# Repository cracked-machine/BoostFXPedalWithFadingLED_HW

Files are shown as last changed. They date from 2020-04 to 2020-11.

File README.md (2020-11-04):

## Boost Pedal with LEDs

- Required Kicad Hardware library: https://github.com/cracked-machine/KicadLibrary
- Related SW project: https://github.com/cracked-machine/BoostFXPedalWithFadingLED__SW

This is a simple opamp-based gain boost circuit for guitar FX pedal.

The sockets and switches are wired directly to the board, they are not panel-mounted. This makes the design simpler but construction becomes more time-consuming. Mechanical layout for the enclosure is below.

Mechanical Layout

This design went through several revisions.

- RevA is a purely analog HW design without any LEDs.
- RevC added a micro-controller to run 8 SMT LEDs in a fading pattern using PWM. RevC uses multiple SPST solid-state switches (DG467) to simplify the footswitch control and replace the bulky and expensive 3PDT mechanical switches often used in guitar FX pedals. Some high frequency signal attenuation could be heard with the DG467 switches. This is probably due to the MOSFET capacitance of the DG467 switches. However, [FFT analysis](OverdrivePedal_RevC/OverDriveSpectrumAnalysis) was inconclusive.
- RevD proposes a design to use a single DPDT Relay to avoid any signal loss issues. However, this revision was not constructed/tested.

Revision|Comments|Schema|Front|Back
:--------:|:--:|:--:|:--:|:---:
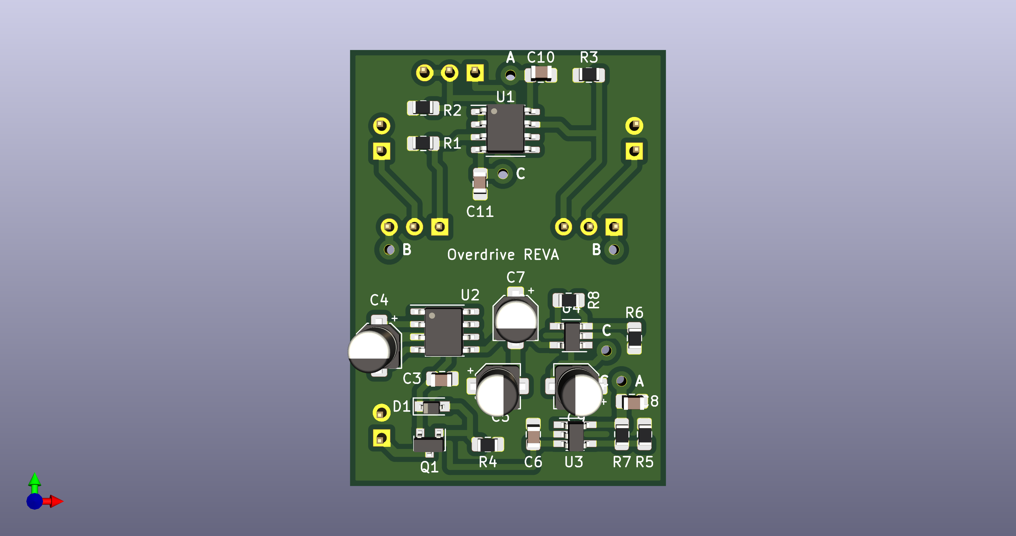
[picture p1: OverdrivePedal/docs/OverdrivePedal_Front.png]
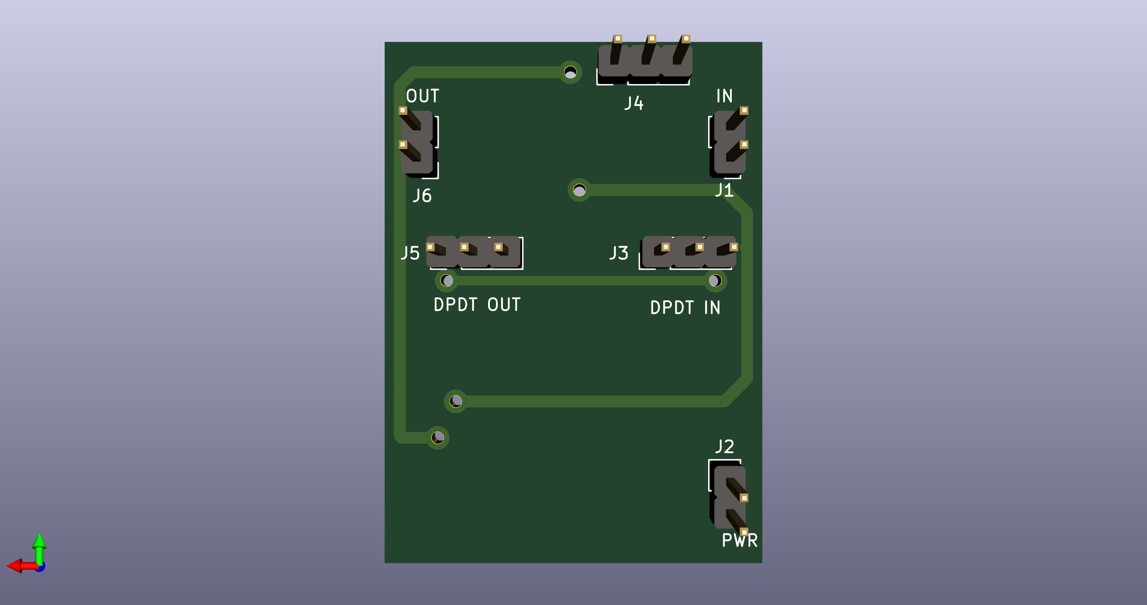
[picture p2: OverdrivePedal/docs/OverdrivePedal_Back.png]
RevA|Without LEDs|[link](OverdrivePedal/docs/OverdrivePedal.pdf)|||
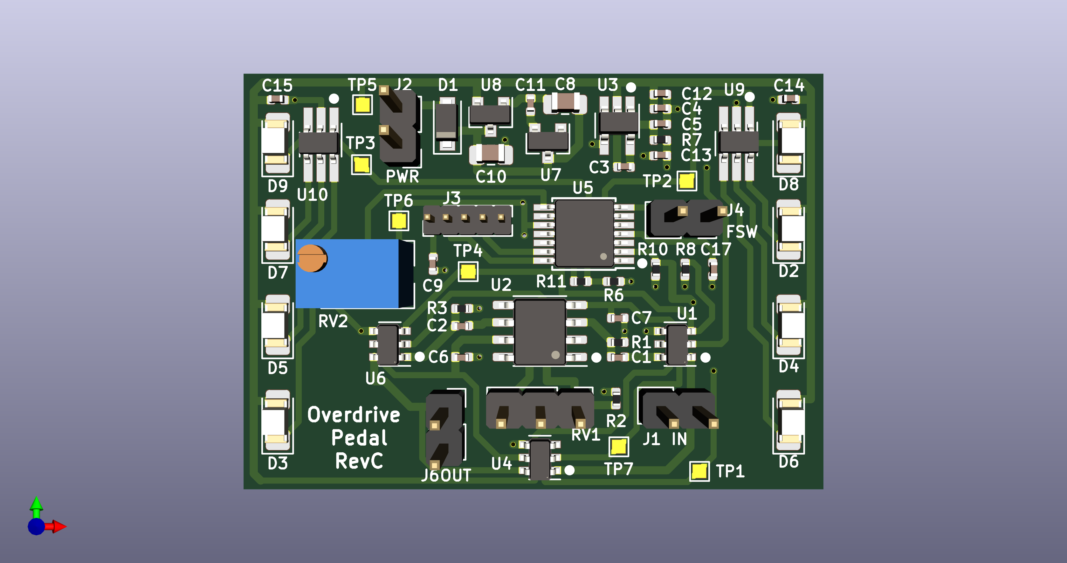
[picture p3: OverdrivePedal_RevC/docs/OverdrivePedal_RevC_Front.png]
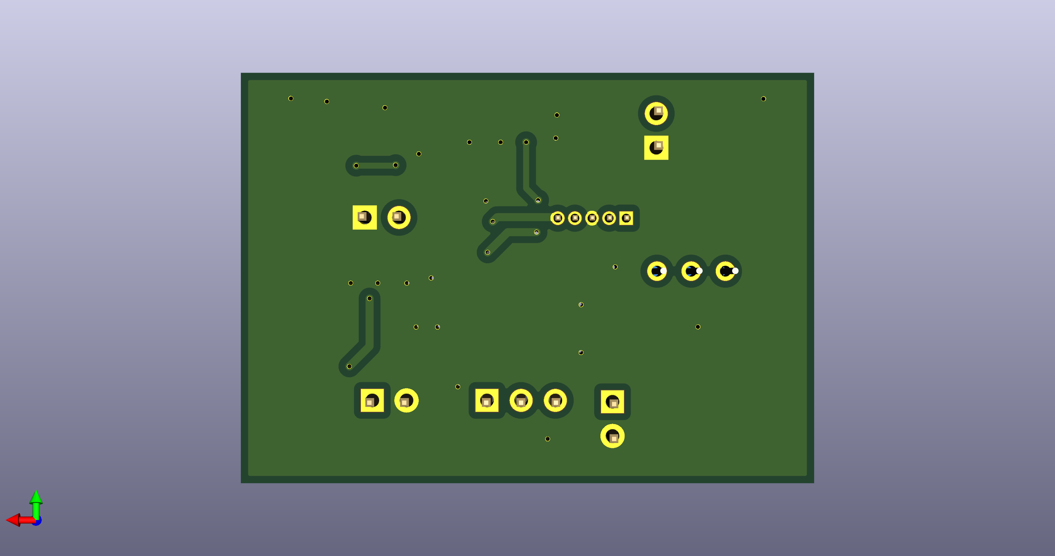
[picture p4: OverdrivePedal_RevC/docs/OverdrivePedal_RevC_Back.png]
RevC|With LEDs, SPST SolidState|[link](OverdrivePedal_RevC/docs/OverdrivePedal_RevC.pdf)|||
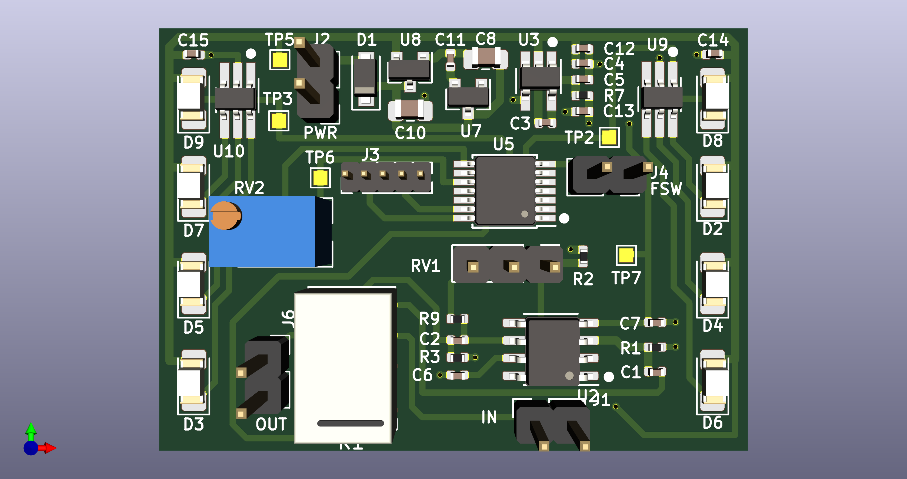
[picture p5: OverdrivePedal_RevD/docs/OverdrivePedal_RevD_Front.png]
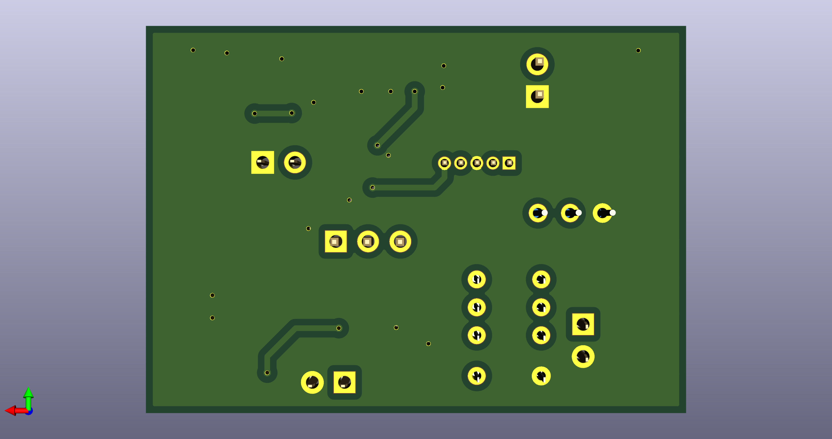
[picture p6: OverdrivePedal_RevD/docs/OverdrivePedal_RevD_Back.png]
RevD|With LEDs, DPDT Relay|[link](OverdrivePedal_RevD/docs/OverdrivePedal_RevD.pdf)|||

### Demo of RevC

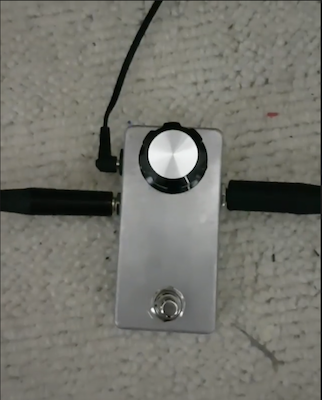
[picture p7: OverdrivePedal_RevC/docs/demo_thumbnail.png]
Boost Pedal with LEDs RevC (https://instagram.flhr4-2.fna.fbcdn.net/v/t50.2886-16/101602450_255417275813723_5445158146007316454_n.mp4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 "Boost Pedal with LEDs RevC")


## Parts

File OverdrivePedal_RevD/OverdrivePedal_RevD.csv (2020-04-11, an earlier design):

Source: | /home/chris/Projects/Hardware/OverdrivePedal/OverdrivePedal_RevB/OverdrivePedal_RevB.sch
Date: | Thu 09 Apr 2020 17:33:00 BST
Tool: | Eeschema 5.1.5-52549c5~86~ubuntu18.04.1
Generator: | /usr/share/kicad/plugins/bom_csv_grouped_by_value.py
Component Count: | 55
Individual Components:
Item | Qty | Reference(s) | Value | LibPart | Footprint | Datasheet
 |  | C1 | C | Device:C | Capacitor_SMD:C_0402_1005Metric | ~
 |  | C2 | C | Device:C | Capacitor_SMD:C_0402_1005Metric | ~
 |  | C3 | 1uF | Device:C | Capacitor_SMD:C_0402_1005Metric | ~
 |  | C4 | 1uF | Device:C | Capacitor_SMD:C_0402_1005Metric | ~
 |  | C5 | 1uF | Device:C | Capacitor_SMD:C_0402_1005Metric | ~
 |  | C6 | 100nF | Device:C | Capacitor_SMD:C_0402_1005Metric | ~
 |  | C7 | 100nF | Device:C | Capacitor_SMD:C_0402_1005Metric | ~
 |  | C8 | 1uF | Device:C | Capacitor_SMD:C_0805_2012Metric_Pad1.15x1.40mm_HandSolder | ~
 |  | C9 | 100nF | Device:C | Capacitor_SMD:C_0402_1005Metric | ~
 |  | C10 | 1uF | Device:C | Capacitor_SMD:C_0805_2012Metric_Pad1.15x1.40mm_HandSolder | ~
 |  | C11 | 10uF | Device:C | Capacitor_SMD:C_0402_1005Metric | ~
 |  | C12 | 10uF | Device:C | Capacitor_SMD:C_0402_1005Metric | ~
 |  | C13 | 1nF | Device:C | Capacitor_SMD:C_0402_1005Metric | ~
 |  | C14 | 1u | Device:C | Capacitor_SMD:C_0402_1005Metric | ~
 |  | C15 | 1u | Device:C | Capacitor_SMD:C_0402_1005Metric | ~
 |  | C16 | 1uF | Device:C | Capacitor_SMD:C_0402_1005Metric | ~
 |  | C17 | 100nF | Device:C | Capacitor_SMD:C_0402_1005Metric | ~
 |  | C18 | 1uF | Device:C | Capacitor_SMD:C_0402_1005Metric | ~
 |  | C19 | 1uF | Device:C | Capacitor_SMD:C_0402_1005Metric | ~
 |  | C20 | 1nF | Device:C | Capacitor_SMD:C_0402_1005Metric | ~
 |  | D1 | BYS12-90 | Device:D_Schottky | Diode_SMD:D_SOD-123F | ~
 |  | D2 | LED | Device:LED | LED_SMD:LED_1206_3216Metric_Pad1.42x1.75mm_HandSolder | ~
 |  | D3 | LED | Device:LED | LED_SMD:LED_1206_3216Metric_Pad1.42x1.75mm_HandSolder | ~
 |  | D4 | LED | Device:LED | LED_SMD:LED_1206_3216Metric_Pad1.42x1.75mm_HandSolder | ~
 |  | D5 | LED | Device:LED | LED_SMD:LED_1206_3216Metric_Pad1.42x1.75mm_HandSolder | ~
 |  | D6 | LED | Device:LED | LED_SMD:LED_1206_3216Metric_Pad1.42x1.75mm_HandSolder | ~
 |  | D7 | LED | Device:LED | LED_SMD:LED_1206_3216Metric_Pad1.42x1.75mm_HandSolder | ~
 |  | D8 | LED | Device:LED | LED_SMD:LED_1206_3216Metric_Pad1.42x1.75mm_HandSolder | ~
 |  | D9 | LED | Device:LED | LED_SMD:LED_1206_3216Metric_Pad1.42x1.75mm_HandSolder | ~
 |  | J1 | AudioJack2-Connector | audiojack2-connector_numbered:AudioJack2-Connector | Connector_PinSocket_2.54mm:PinSocket_1x02_P2.54mm_Vertical
 |  | J2 | Barrel_Jack | Connector:Barrel_Jack | Connector_PinHeader_2.54mm:PinHeader_1x02_P2.54mm_Vertical | ~
 |  | J3 | Conn_01x05 | Connector_Generic:Conn_01x05 | Connector_PinSocket_2.54mm:PinSocket_1x05_P2.54mm_Vertical | ~
 |  | J4 | SW_SPST | Switch:SW_SPST | Connector_PinSocket_2.54mm:PinSocket_1x02_P2.54mm_Vertical | ~
 |  | J6 | AudioJack2-Connector | audiojack2-connector_numbered:AudioJack2-Connector | Connector_PinSocket_2.54mm:PinSocket_1x02_P2.54mm_Vertical
 |  | R1 | 22M | Device:R | Resistor_SMD:R_0402_1005Metric | ~
 |  | R2 | 2K7 | Device:R | Resistor_SMD:R_0402_1005Metric | ~
 |  | R3 | 10K | Device:R | Resistor_SMD:R_0402_1005Metric | ~
 |  | R4 | 10K | Device:R | Resistor_SMD:R_0402_1005Metric | ~
 |  | R5 | 100R | Device:R | Resistor_SMD:R_0402_1005Metric | ~
 |  | R7 | 100R | Device:R | Resistor_SMD:R_0402_1005Metric | ~
 |  | R8 | 10K | Device:R | Resistor_SMD:R_0402_1005Metric | ~
 |  | R10 | 10K | Device:R | Resistor_SMD:R_0402_1005Metric | ~
 |  | R11 | 10K | Device:R | Resistor_SMD:R_0402_1005Metric | ~
 |  | RV1 | B10K | Device:R_POT | Connector_PinHeader_2.54mm:PinHeader_1x03_P2.54mm_Vertical | ~
 |  | U1 | DG468DV_T1_E3 | DG46x:DG468DV_T1_E3 | Package_SO:TSOP-6_1.65x3.05mm_P0.95mm | https://www.vishay.com/docs/74413/dg467.pdf
 |  | U2 | TL071 | Amplifier_Operational:TL071 | Package_SO:SOIC-8_3.9x4.9mm_P1.27mm | http://www.ti.com/lit/ds/symlink/tl071.pdf
 |  | U3 | TPS60400 | TPS6040x:TPS60400 | Package_TO_SOT_SMD:SOT-23-5_HandSoldering | http://www.ti.com/lit/ds/symlink/tps60402.pdf
 |  | U4 | DG468DV_T1_E3 | DG46x:DG468DV_T1_E3 | Package_SO:TSOP-6_1.65x3.05mm_P0.95mm | https://www.vishay.com/docs/74413/dg467.pdf
 |  | U5 | STM32L011D4Px | MCU_ST_STM32L0:STM32L011D4Px | Package_SO:TSSOP-14_4.4x5mm_P0.65mm | http://www.st.com/st-web-ui/static/active/en/resource/technical/document/datasheet/DM00206508.pdf
 |  | U6 | DG468DV_T1_E3 | DG46x:DG468DV_T1_E3 | Package_SO:TSOP-6_1.65x3.05mm_P0.95mm | https://www.vishay.com/docs/74413/dg467.pdf
 |  | U7 | SE8233X2 | Regulator_Linear:MCP1700-5002E_SOT23 | Package_TO_SOT_SMD:SOT-23 | https://datasheet.lcsc.com/szlcsc/1910181014_Seaward-Elec-SE8250X2_C437589.pdf
 |  | U8 | SE8250X2 | Regulator_Linear:MCP1700-5002E_SOT23 | Package_TO_SOT_SMD:SOT-23 | https://datasheet.lcsc.com/szlcsc/1910181014_Seaward-Elec-SE8250X2_C437589.pdf
 |  | U9 | PAM2812 | PAM2812:PAM2812 | Package_TO_SOT_SMD:TSOT-23-6_HandSoldering | https://docs.rs-online.com/eeb3/0900766b81268ced.pdf
 |  | U10 | PAM2812 | PAM2812:PAM2812 | Package_TO_SOT_SMD:TSOT-23-6_HandSoldering | https://docs.rs-online.com/eeb3/0900766b81268ced.pdf
 |  | U11 | TPS60400 | TPS6040x:TPS60400 | Package_TO_SOT_SMD:SOT-23-5_HandSoldering | http://www.ti.com/lit/ds/symlink/tps60402.pdf
Collated Components:
Item | Qty | Reference(s) | Value | LibPart | Footprint | Datasheet
1 | 2 | C1, C2 | C | Device:C | Capacitor_SMD:C_0402_1005Metric | ~
2 | 6 | C3, C4, C5, C16, C18, C19 | 1uF | Device:C | Capacitor_SMD:C_0402_1005Metric | ~
3 | 4 | C6, C7, C9, C17 | 100nF | Device:C | Capacitor_SMD:C_0402_1005Metric | ~
4 | 2 | C8, C10 | 1uF | Device:C | Capacitor_SMD:C_0805_2012Metric_Pad1.15x1.40mm_HandSolder | ~
5 | 2 | C11, C12 | 10uF | Device:C | Capacitor_SMD:C_0402_1005Metric | ~
6 | 2 | C13, C20 | 1nF | Device:C | Capacitor_SMD:C_0402_1005Metric | ~
7 | 2 | C14, C15 | 1u | Device:C | Capacitor_SMD:C_0402_1005Metric | ~
8 | 1 | D1 | BYS12-90 | Device:D_Schottky | Diode_SMD:D_SOD-123F | ~
9 | 8 | D2, D3, D4, D5, D6, D7, D8, D9 | LED | Device:LED | LED_SMD:LED_1206_3216Metric_Pad1.42x1.75mm_HandSolder | ~
10 | 2 | J1, J6 | AudioJack2-Connector | audiojack2-connector_numbered:AudioJack2-Connector | Connector_PinSocket_2.54mm:PinSocket_1x02_P2.54mm_Vertical
11 | 1 | J2 | Barrel_Jack | Connector:Barrel_Jack | Connector_PinHeader_2.54mm:PinHeader_1x02_P2.54mm_Vertical | ~
12 | 1 | J3 | Conn_01x05 | Connector_Generic:Conn_01x05 | Connector_PinSocket_2.54mm:PinSocket_1x05_P2.54mm_Vertical | ~
13 | 1 | J4 | SW_SPST | Switch:SW_SPST | Connector_PinSocket_2.54mm:PinSocket_1x02_P2.54mm_Vertical | ~
14 | 1 | R1 | 22M | Device:R | Resistor_SMD:R_0402_1005Metric | ~
15 | 1 | R2 | 2K7 | Device:R | Resistor_SMD:R_0402_1005Metric | ~
16 | 5 | R3, R4, R8, R10, R11 | 10K | Device:R | Resistor_SMD:R_0402_1005Metric | ~
17 | 2 | R5, R7 | 100R | Device:R | Resistor_SMD:R_0402_1005Metric | ~
18 | 1 | RV1 | B10K | Device:R_POT | Connector_PinHeader_2.54mm:PinHeader_1x03_P2.54mm_Vertical | ~
19 | 3 | U1, U4, U6 | DG468DV_T1_E3 | DG46x:DG468DV_T1_E3 | Package_SO:TSOP-6_1.65x3.05mm_P0.95mm | https://www.vishay.com/docs/74413/dg467.pdf
20 | 1 | U2 | TL071 | Amplifier_Operational:TL071 | Package_SO:SOIC-8_3.9x4.9mm_P1.27mm | http://www.ti.com/lit/ds/symlink/tl071.pdf
21 | 2 | U3, U11 | TPS60400 | TPS6040x:TPS60400 | Package_TO_SOT_SMD:SOT-23-5_HandSoldering | http://www.ti.com/lit/ds/symlink/tps60402.pdf
22 | 1 | U5 | STM32L011D4Px | MCU_ST_STM32L0:STM32L011D4Px | Package_SO:TSSOP-14_4.4x5mm_P0.65mm | http://www.st.com/st-web-ui/static/active/en/resource/technical/document/datasheet/DM00206508.pdf
23 | 1 | U7 | SE8233X2 | Regulator_Linear:MCP1700-5002E_SOT23 | Package_TO_SOT_SMD:SOT-23 | https://datasheet.lcsc.com/szlcsc/1910181014_Seaward-Elec-SE8250X2_C437589.pdf
24 | 1 | U8 | SE8250X2 | Regulator_Linear:MCP1700-5002E_SOT23 | Package_TO_SOT_SMD:SOT-23 | https://datasheet.lcsc.com/szlcsc/1910181014_Seaward-Elec-SE8250X2_C437589.pdf
25 | 2 | U9, U10 | PAM2812 | PAM2812:PAM2812 | Package_TO_SOT_SMD:TSOT-23-6_HandSoldering | https://docs.rs-online.com/eeb3/0900766b81268ced.pdf

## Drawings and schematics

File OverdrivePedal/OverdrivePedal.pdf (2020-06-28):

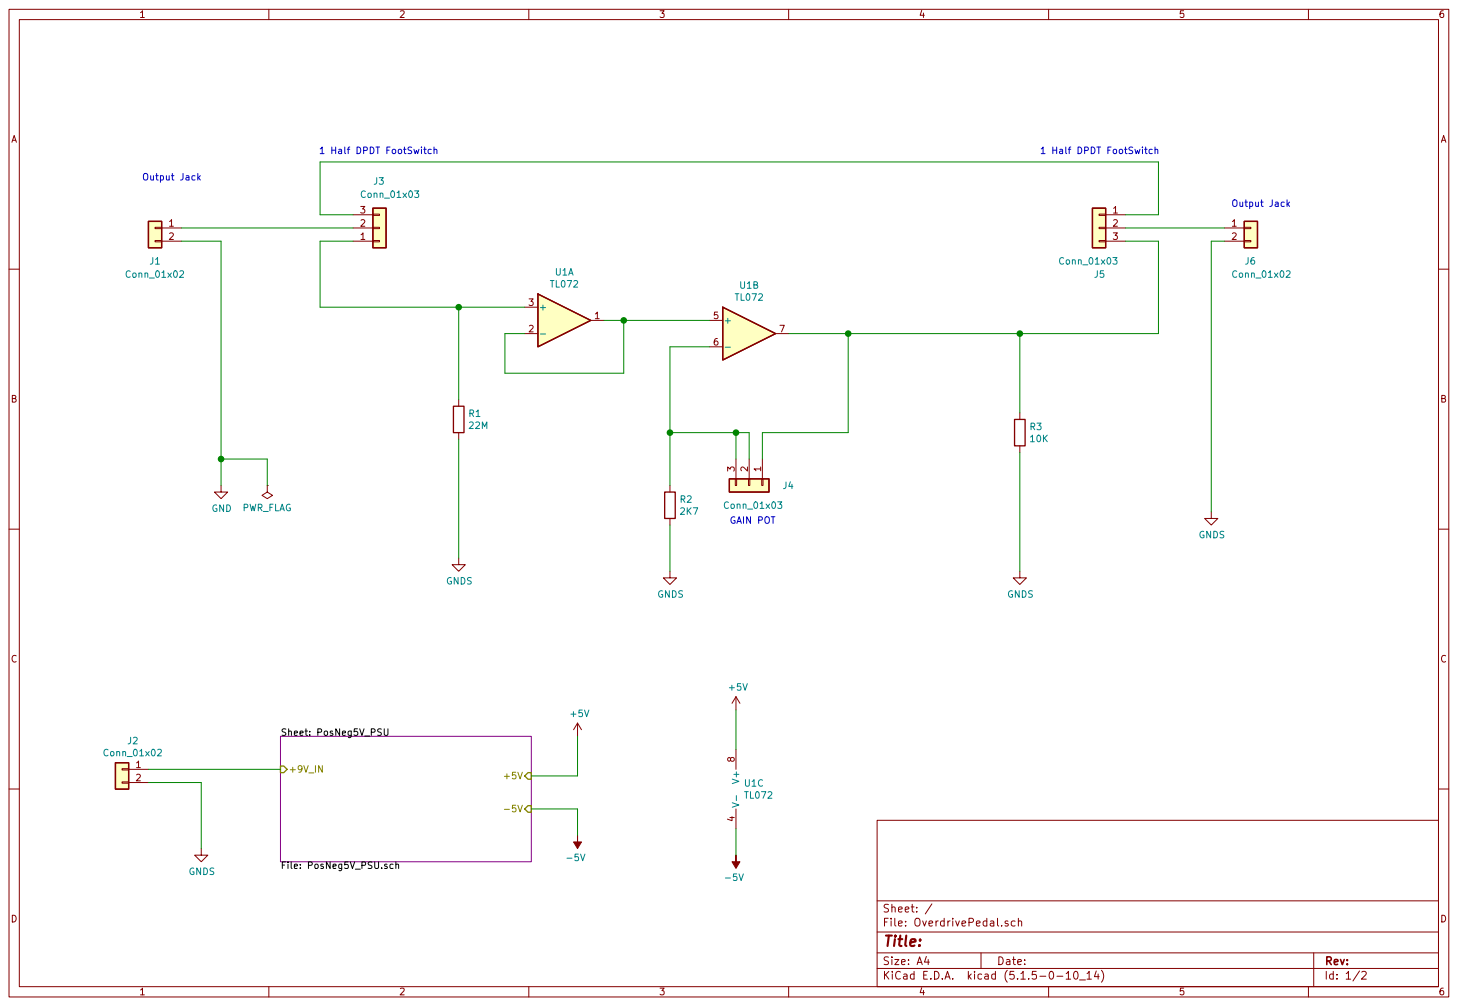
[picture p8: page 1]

Id: 1/2 Title: File: OverdrivePedal.sch Sheet: / Sheet: PosNeg5V_PSU

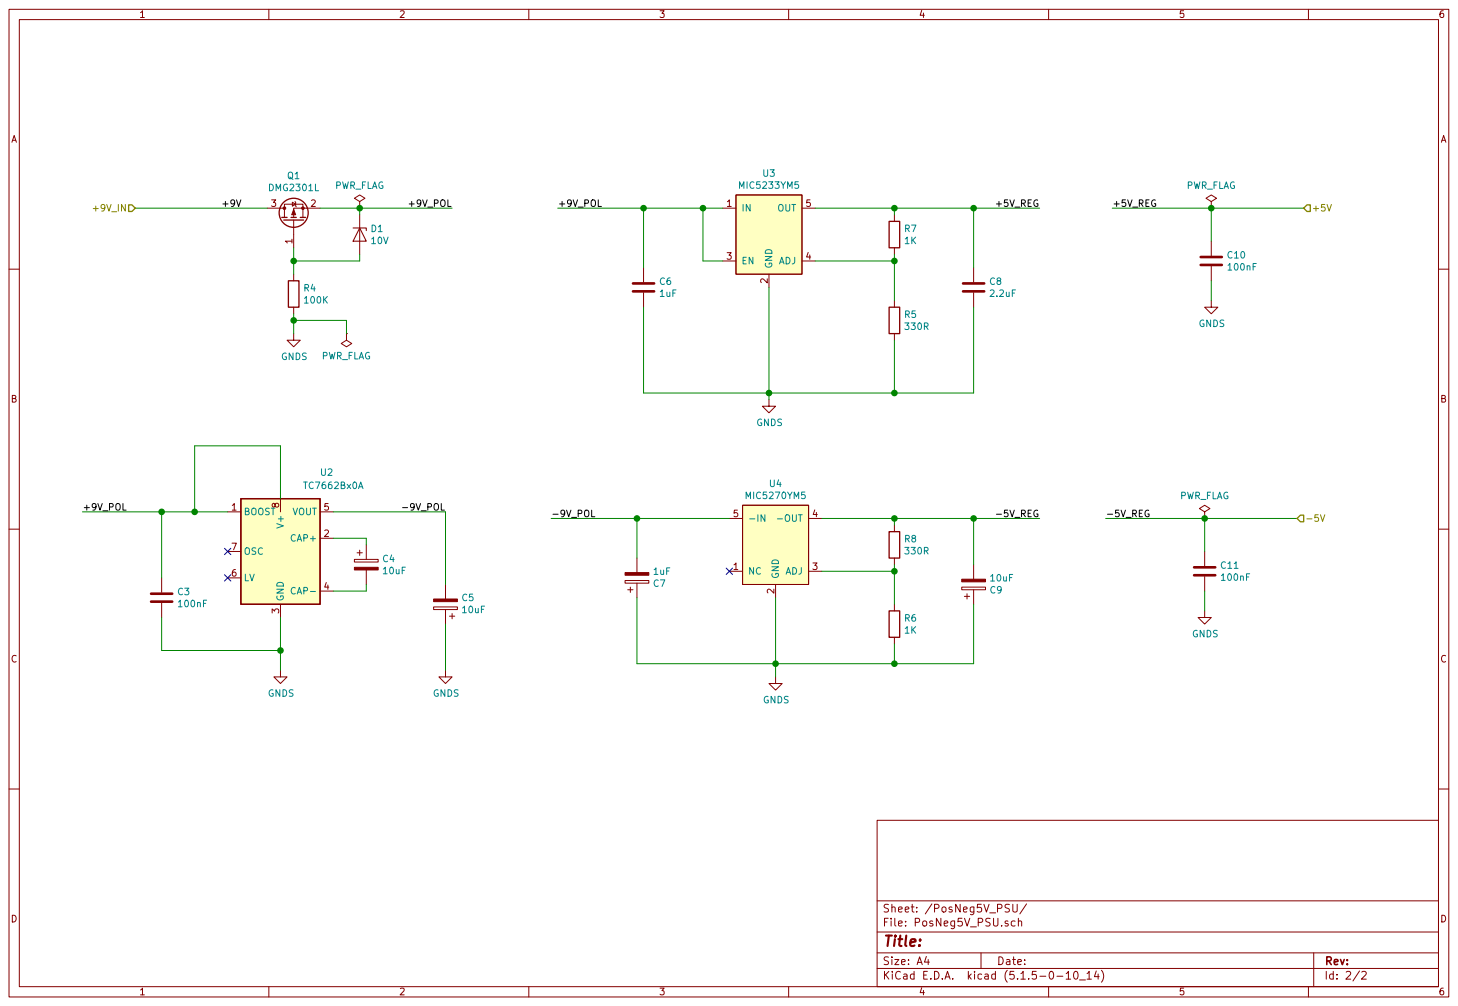
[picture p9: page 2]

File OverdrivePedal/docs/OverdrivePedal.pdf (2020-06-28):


Id: 1/2 Title: File: OverdrivePedal.sch Sheet: / Sheet: PosNeg5V_PSU


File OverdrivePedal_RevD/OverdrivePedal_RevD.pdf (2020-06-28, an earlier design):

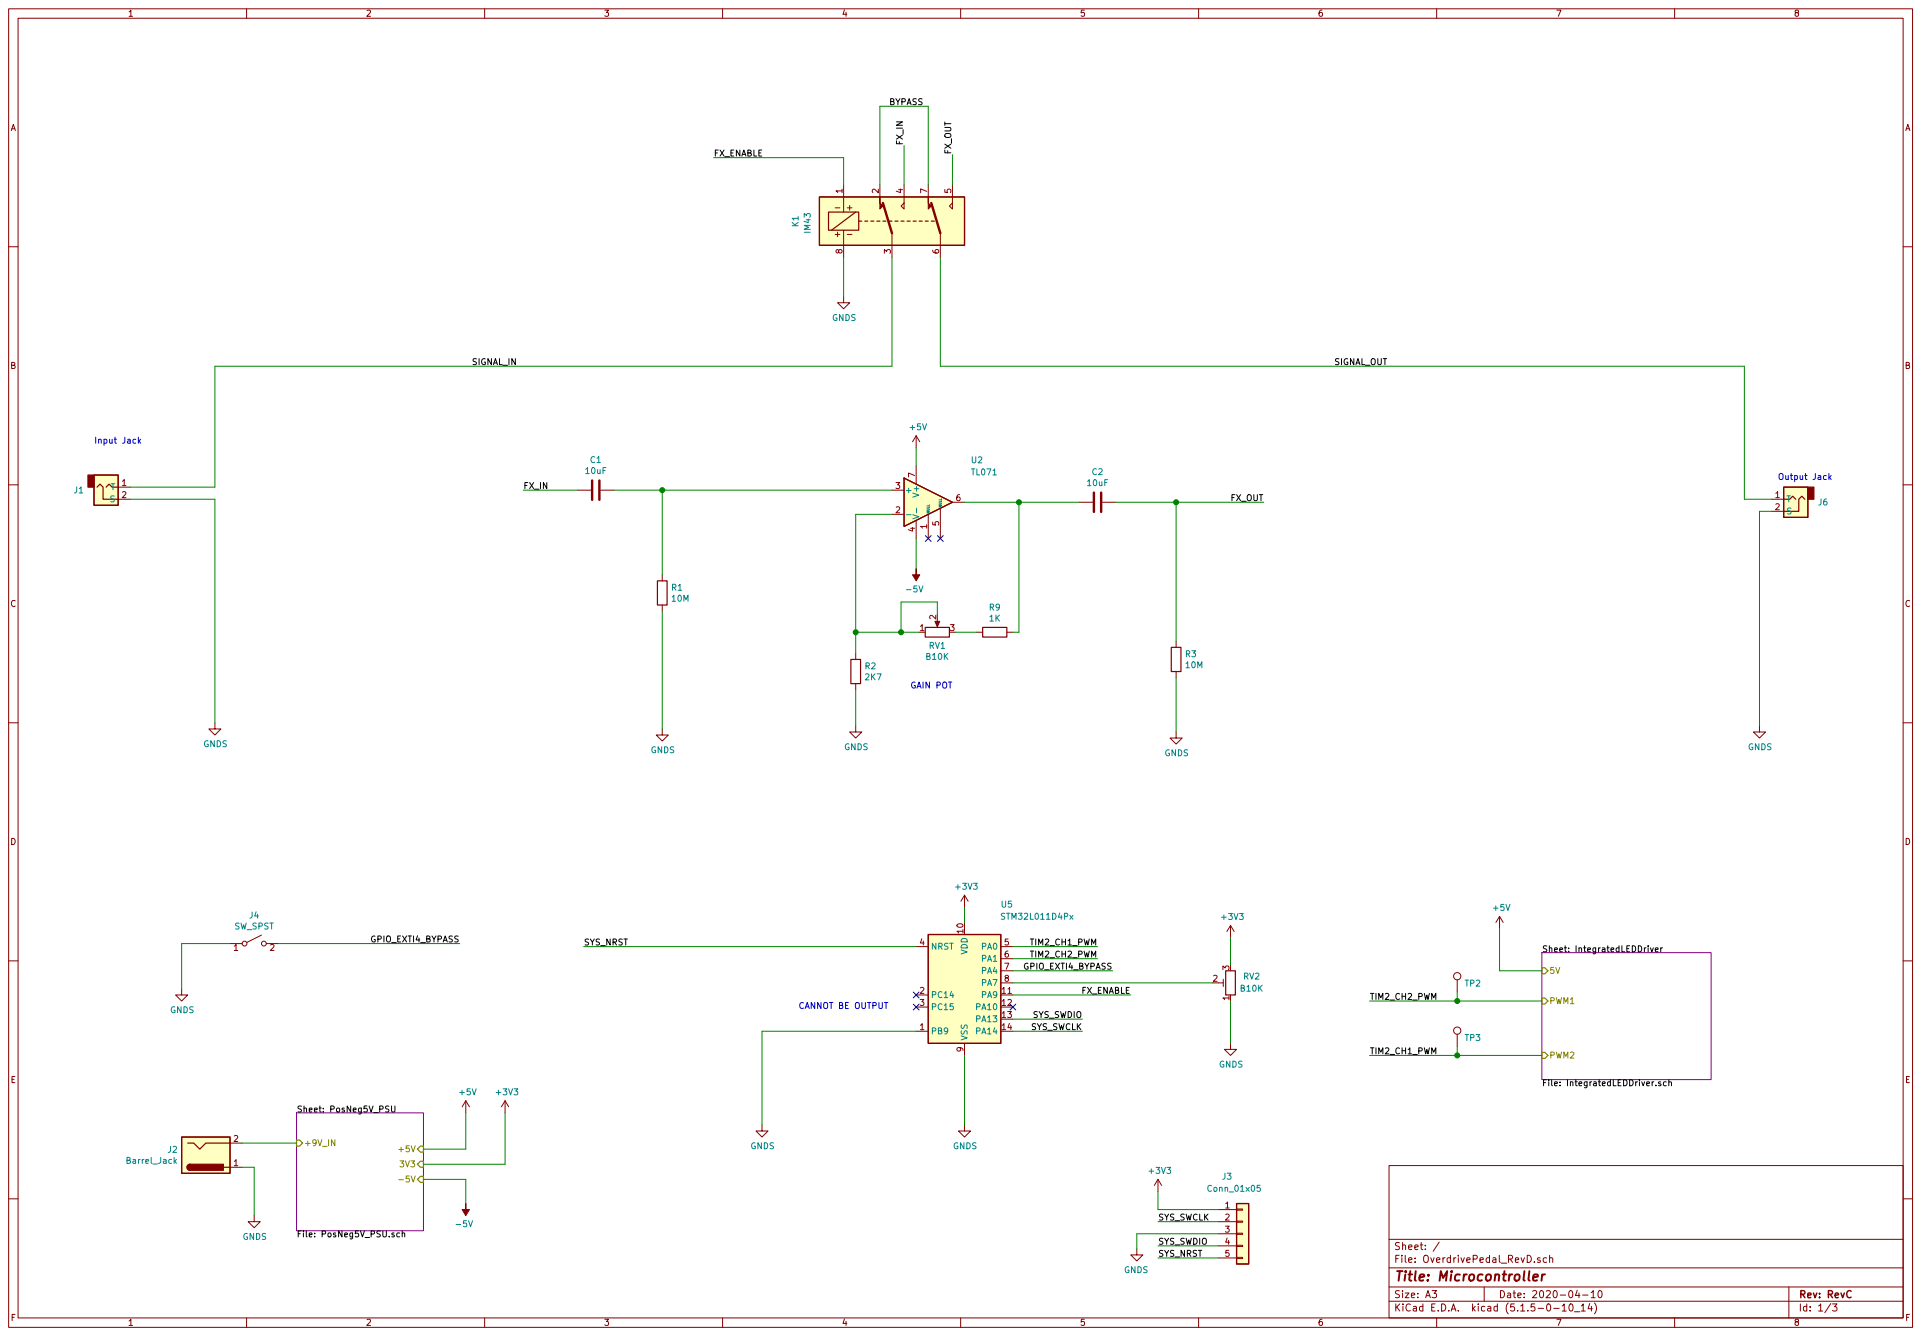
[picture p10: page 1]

BYPASS FX_IN

File: OverdrivePedal_RevD.sch Sheet: / Sheet: PosNeg5V_PSU

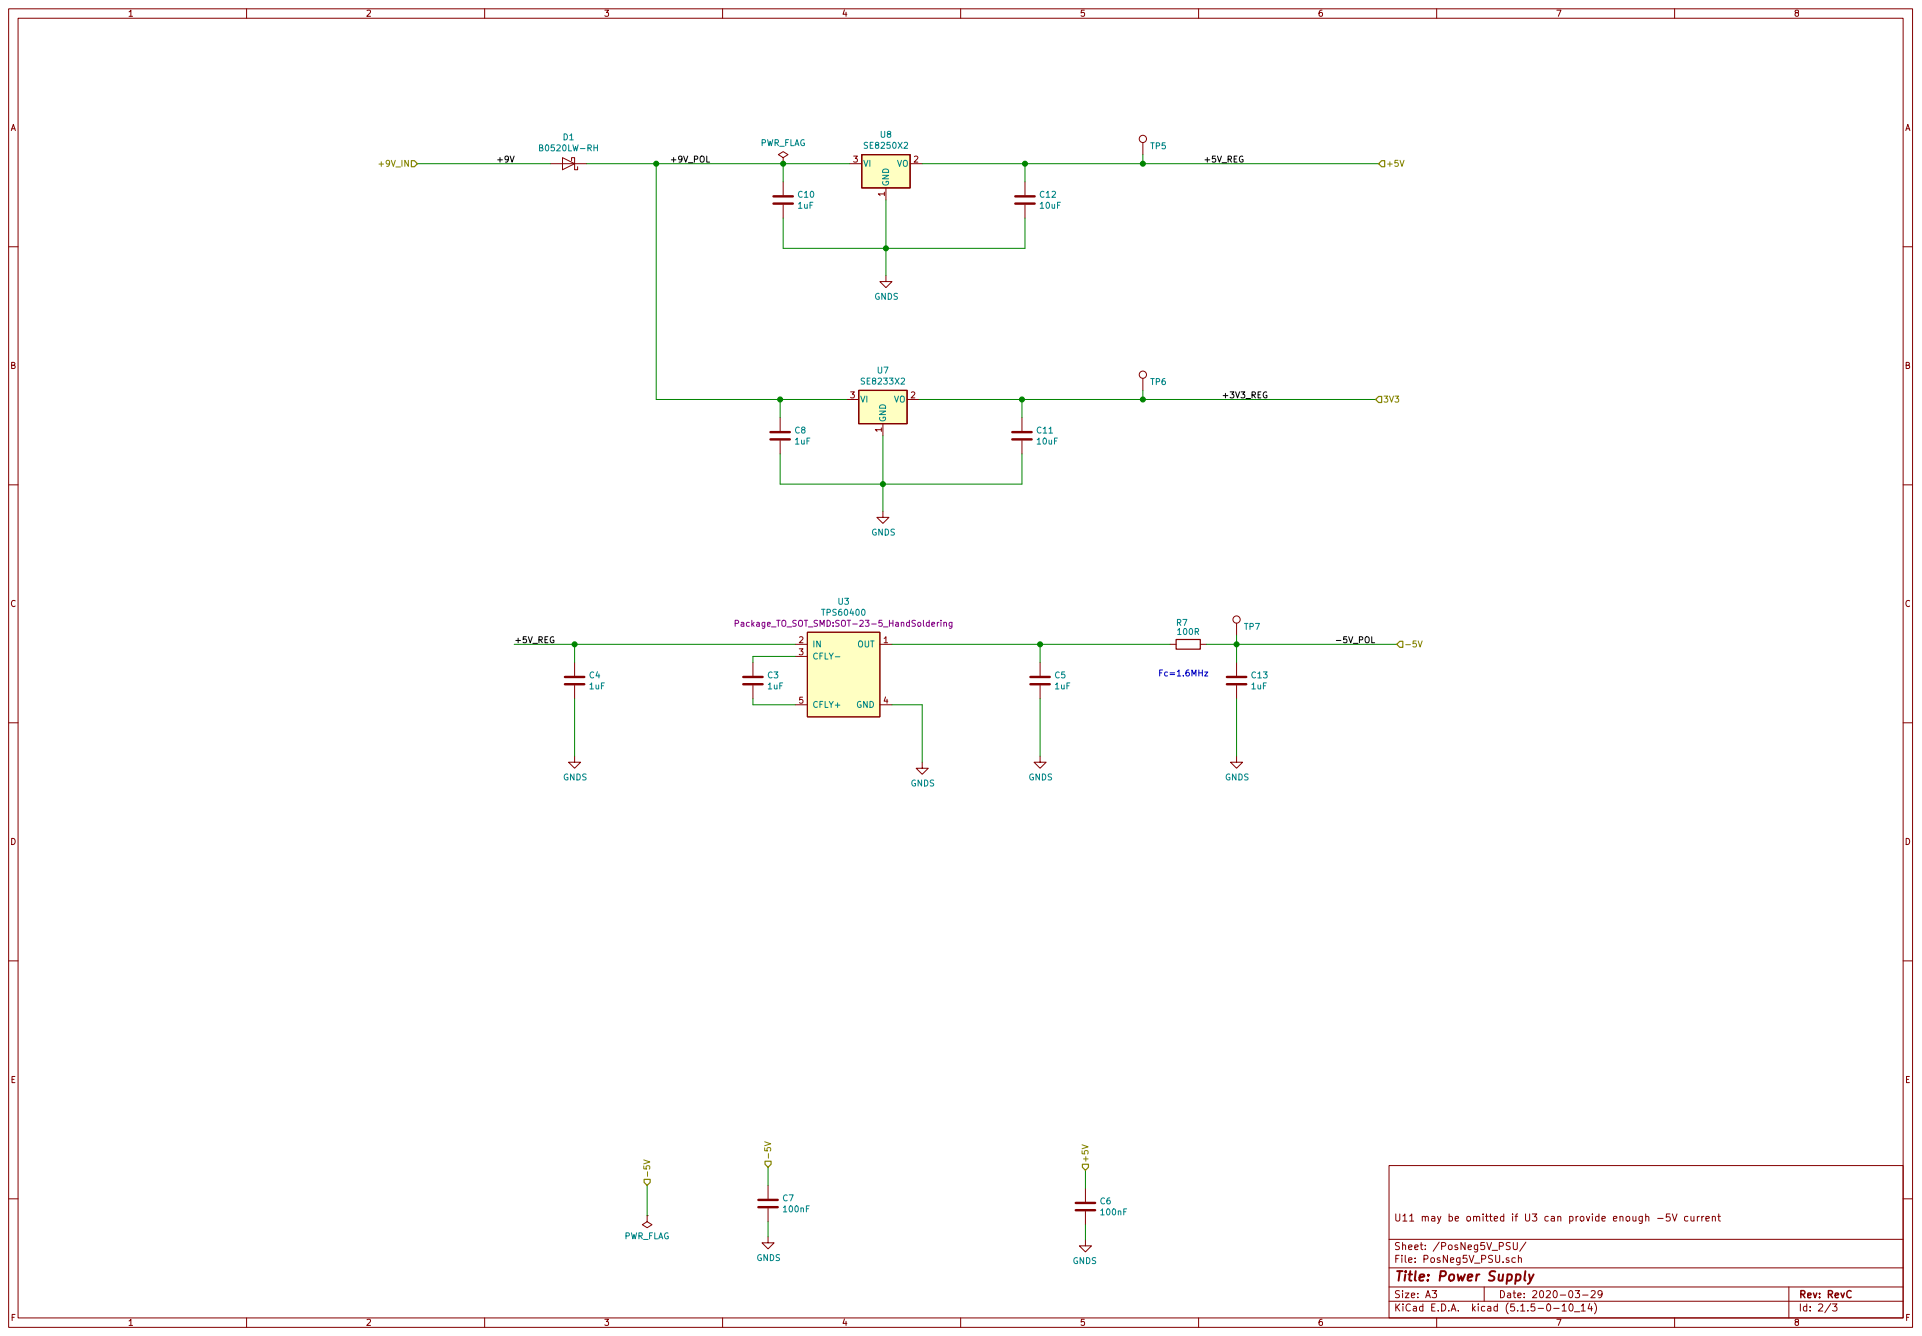
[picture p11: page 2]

1 VO 2 VI 3 U8 SE8250X2 GNDS GNDS C5

U11 may be omitted if U3 can provide enough -5V current

Sheet: /PosNeg5V_PSU/
File: PosNeg5V_PSU.sch
Id: 2/3 Title: Power Supply

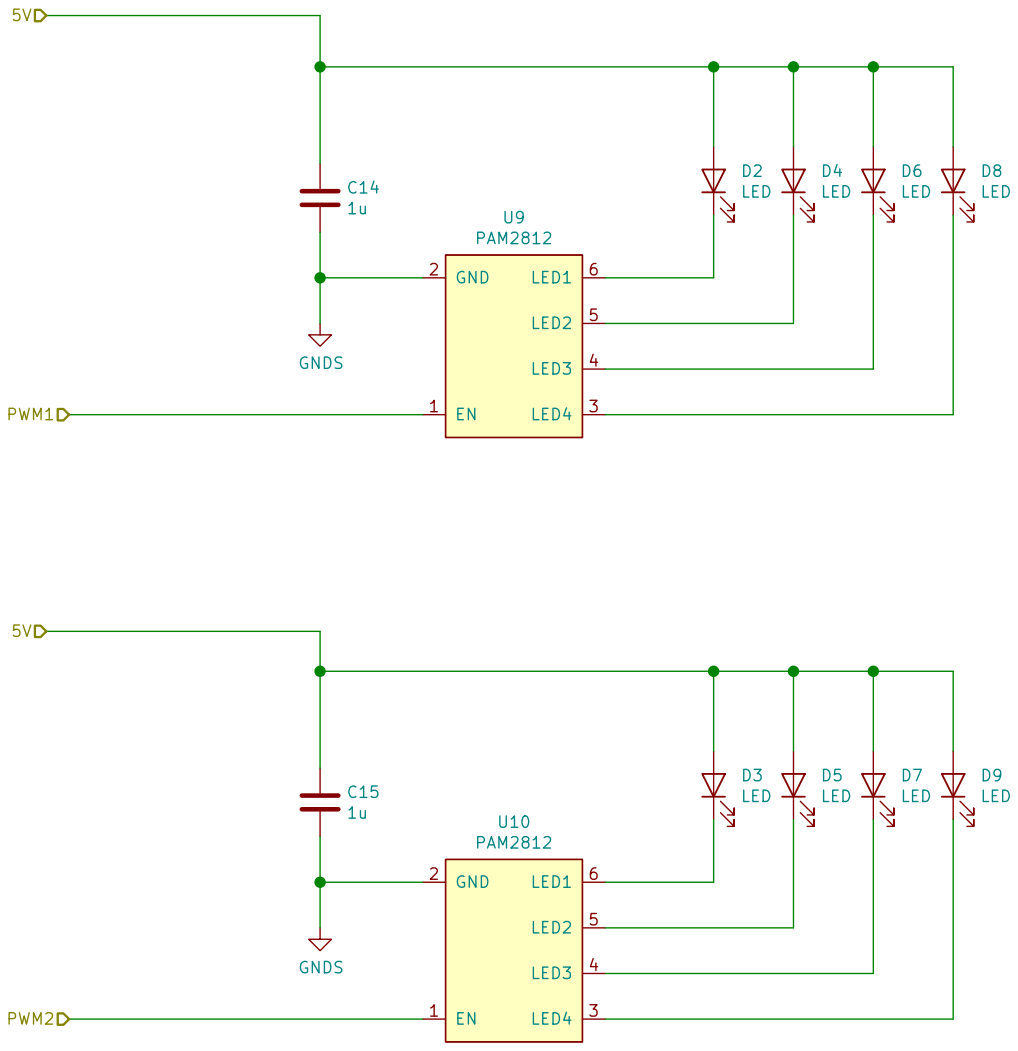
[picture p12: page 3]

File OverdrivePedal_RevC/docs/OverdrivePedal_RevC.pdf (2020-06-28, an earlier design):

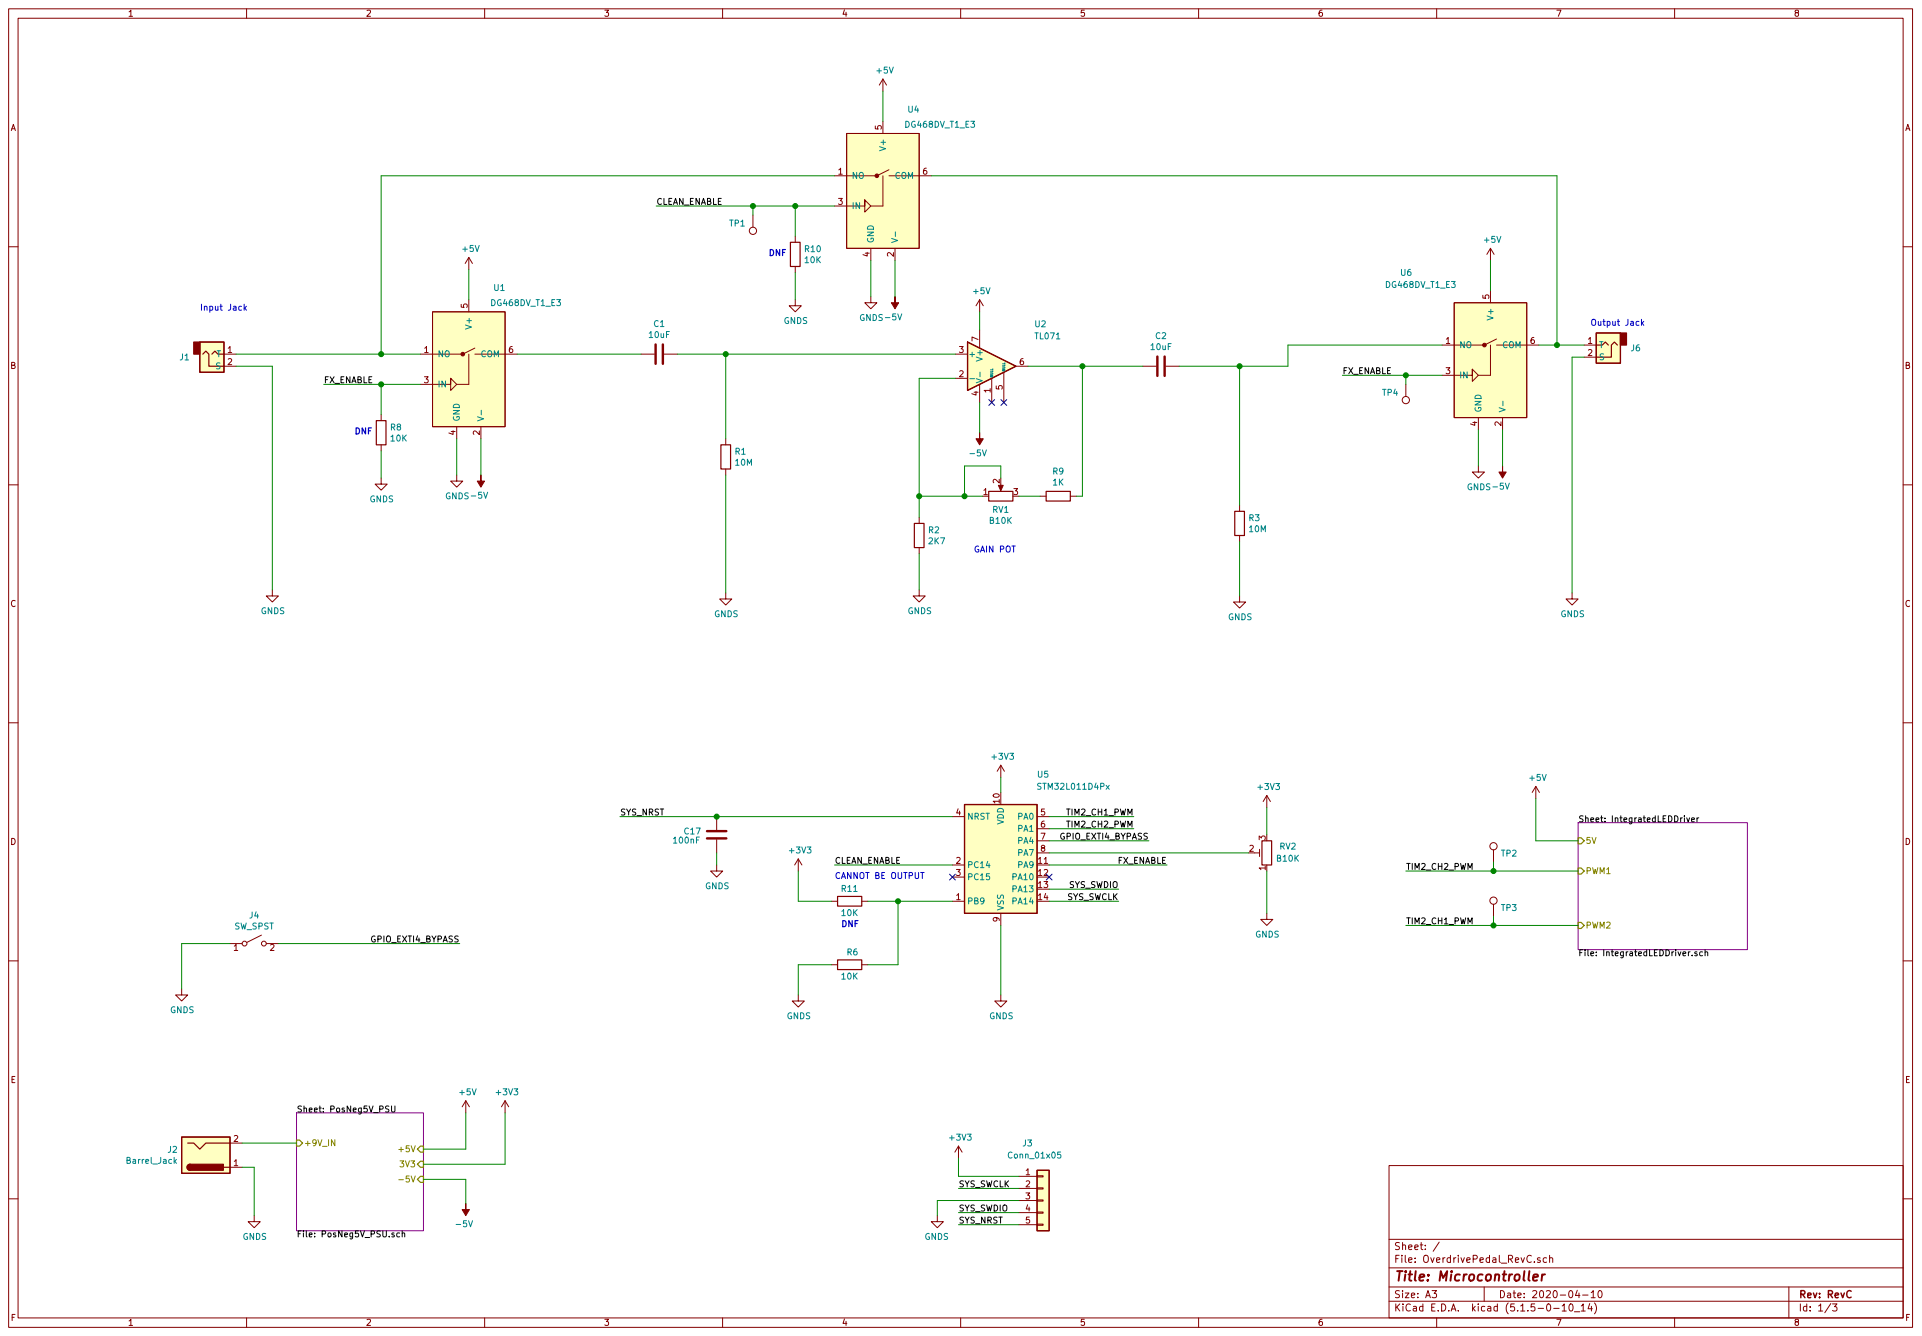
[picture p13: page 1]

File: OverdrivePedal_RevC.sch Sheet: / Sheet: PosNeg5V_PSU

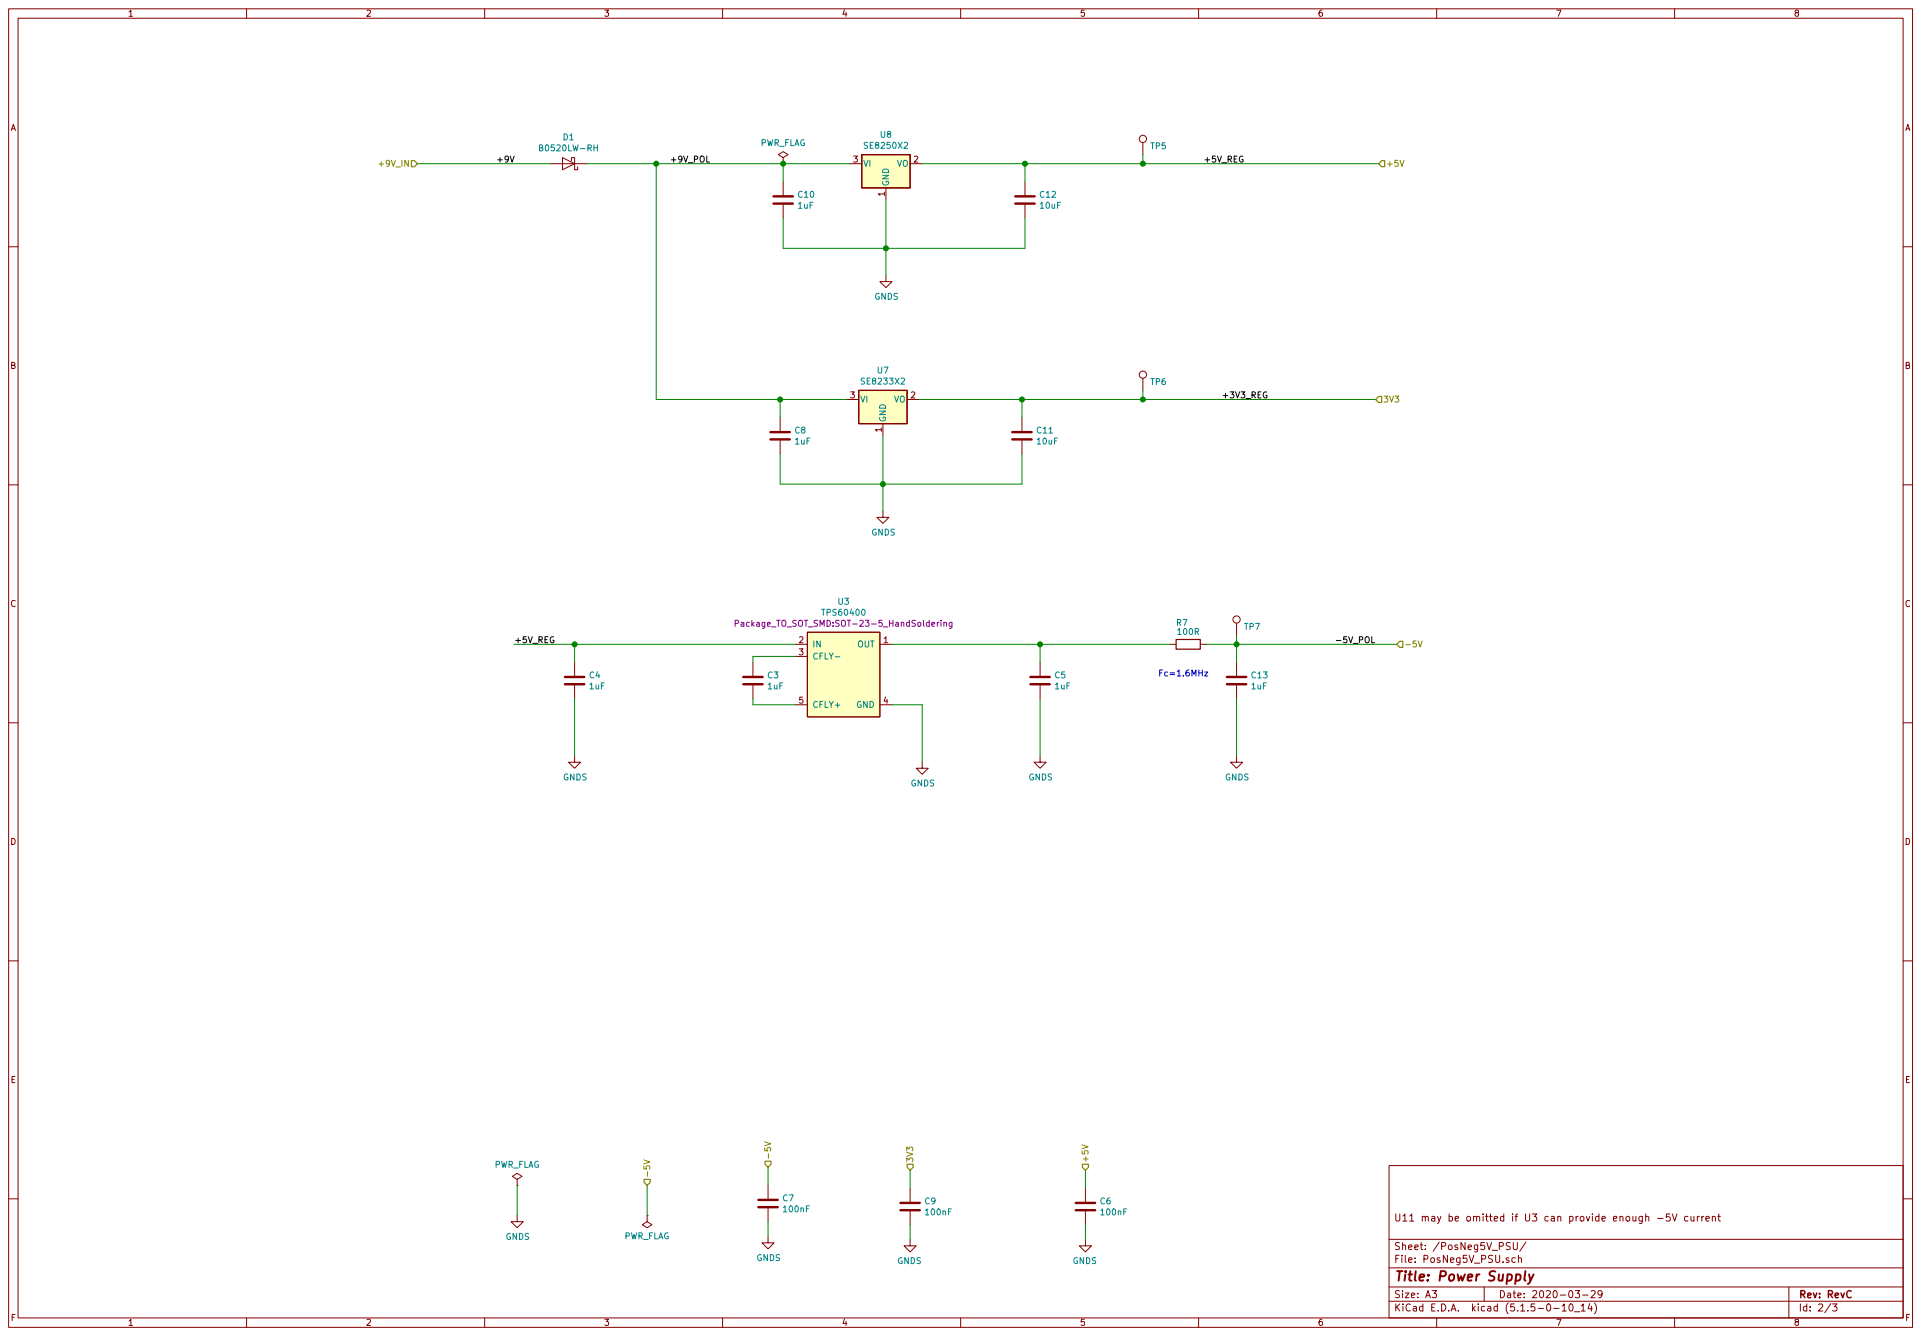
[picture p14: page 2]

U11 may be omitted if U3 can provide enough -5V current

Sheet: /PosNeg5V_PSU/
File: PosNeg5V_PSU.sch
Id: 2/3 Title: Power Supply


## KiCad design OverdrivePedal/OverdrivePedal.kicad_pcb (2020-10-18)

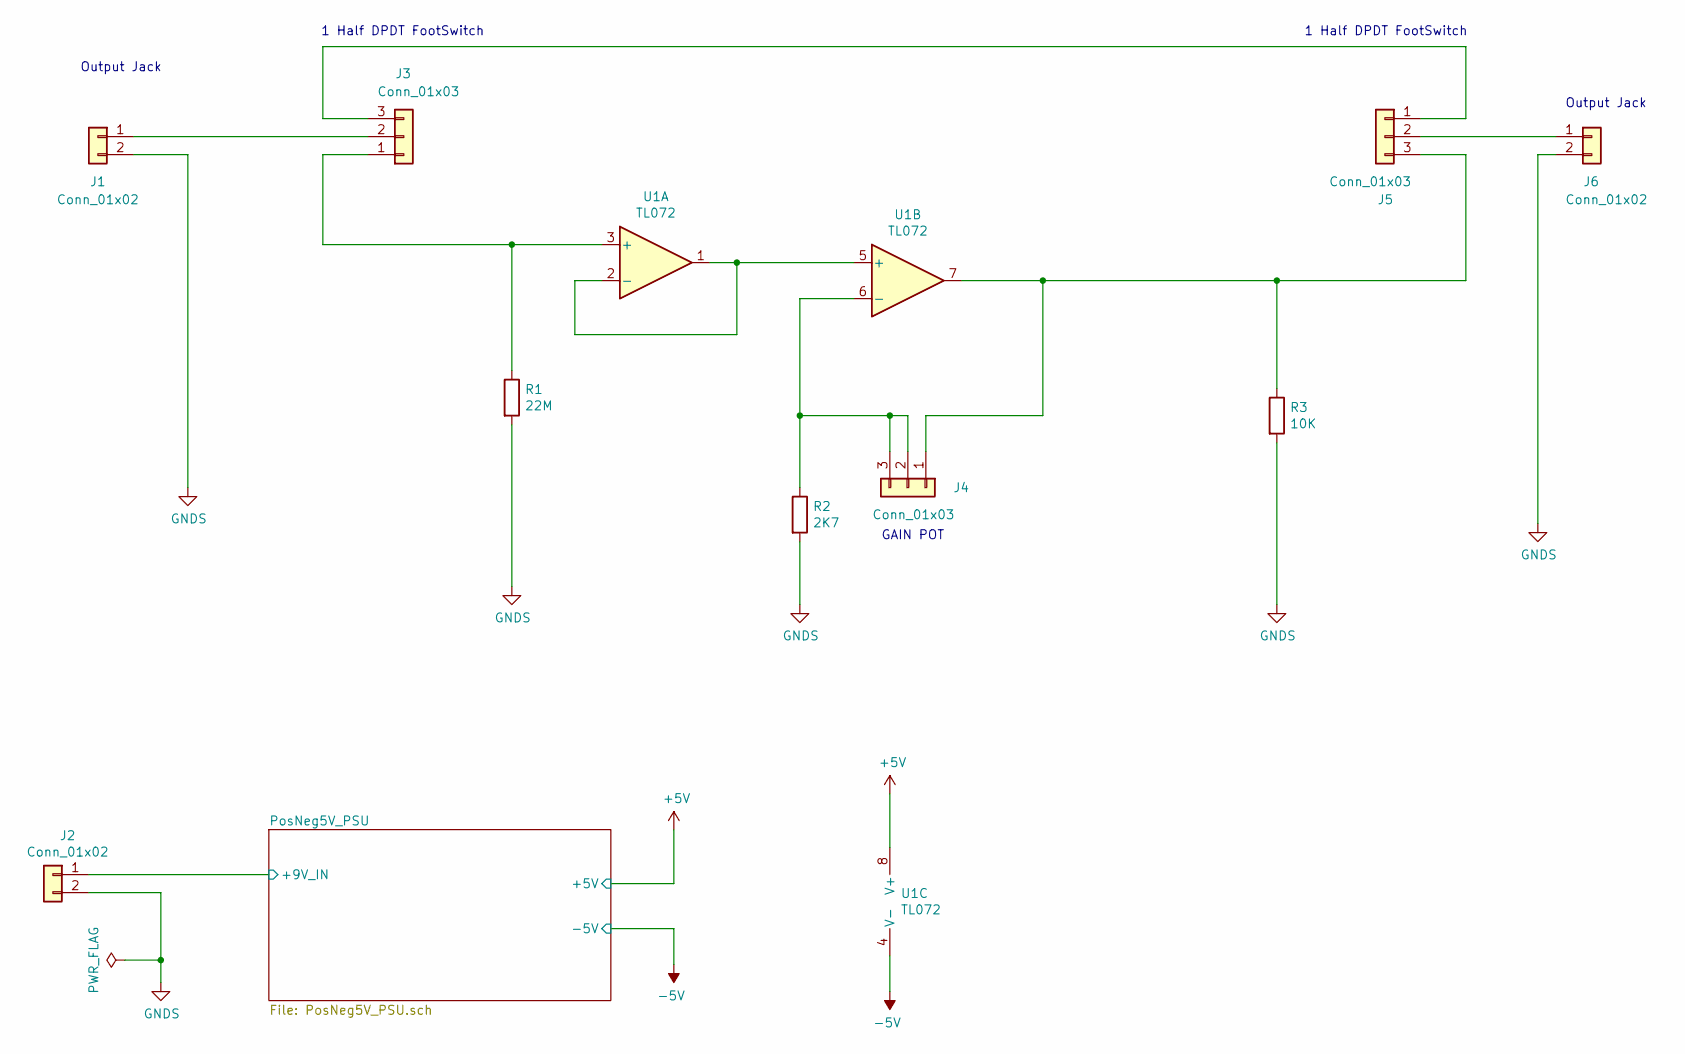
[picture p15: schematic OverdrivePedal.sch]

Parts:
J1, J2, J6: Conn_01x02; PinHeader_1x02_P2.54mm_Vertical
J3, J4, J5: Conn_01x03; PinHeader_1x03_P2.54mm_Vertical
R1: 22M; R_0805_2012Metric_Pad1.15x1.40mm_HandSolder
R2: 2K7; R_0805_2012Metric_Pad1.15x1.40mm_HandSolder
R3: 10K; R_0805_2012Metric_Pad1.15x1.40mm_HandSolder
U1: TL072; SOIC-8_3.9x4.9mm_P1.27mm

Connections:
+5V: U1.8 (V+); also elsewhere on the board
-5V: U1.4 (V-); also elsewhere on the board
/PosNeg5V_PSU/+9V_IN: J2.1; also elsewhere on the board
GNDS: J1.2, J2.2, J6.2, R1.2, R2.2, R3.2; also elsewhere on the board
unnamed: J1.1, J3.2
unnamed: J3.1, R1.1, U1.3 (+)
unnamed: J3.3, J5.1
unnamed: J4.1, J5.3, R3.1, U1.7
unnamed: J4.2, J4.3, R2.1, U1.6 (-)
unnamed: J5.2, J6.1
unnamed: U1.1, U1.2 (-), U1.5 (+)

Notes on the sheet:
GAIN POT
Output Jack
1 Half DPDT FootSwitch

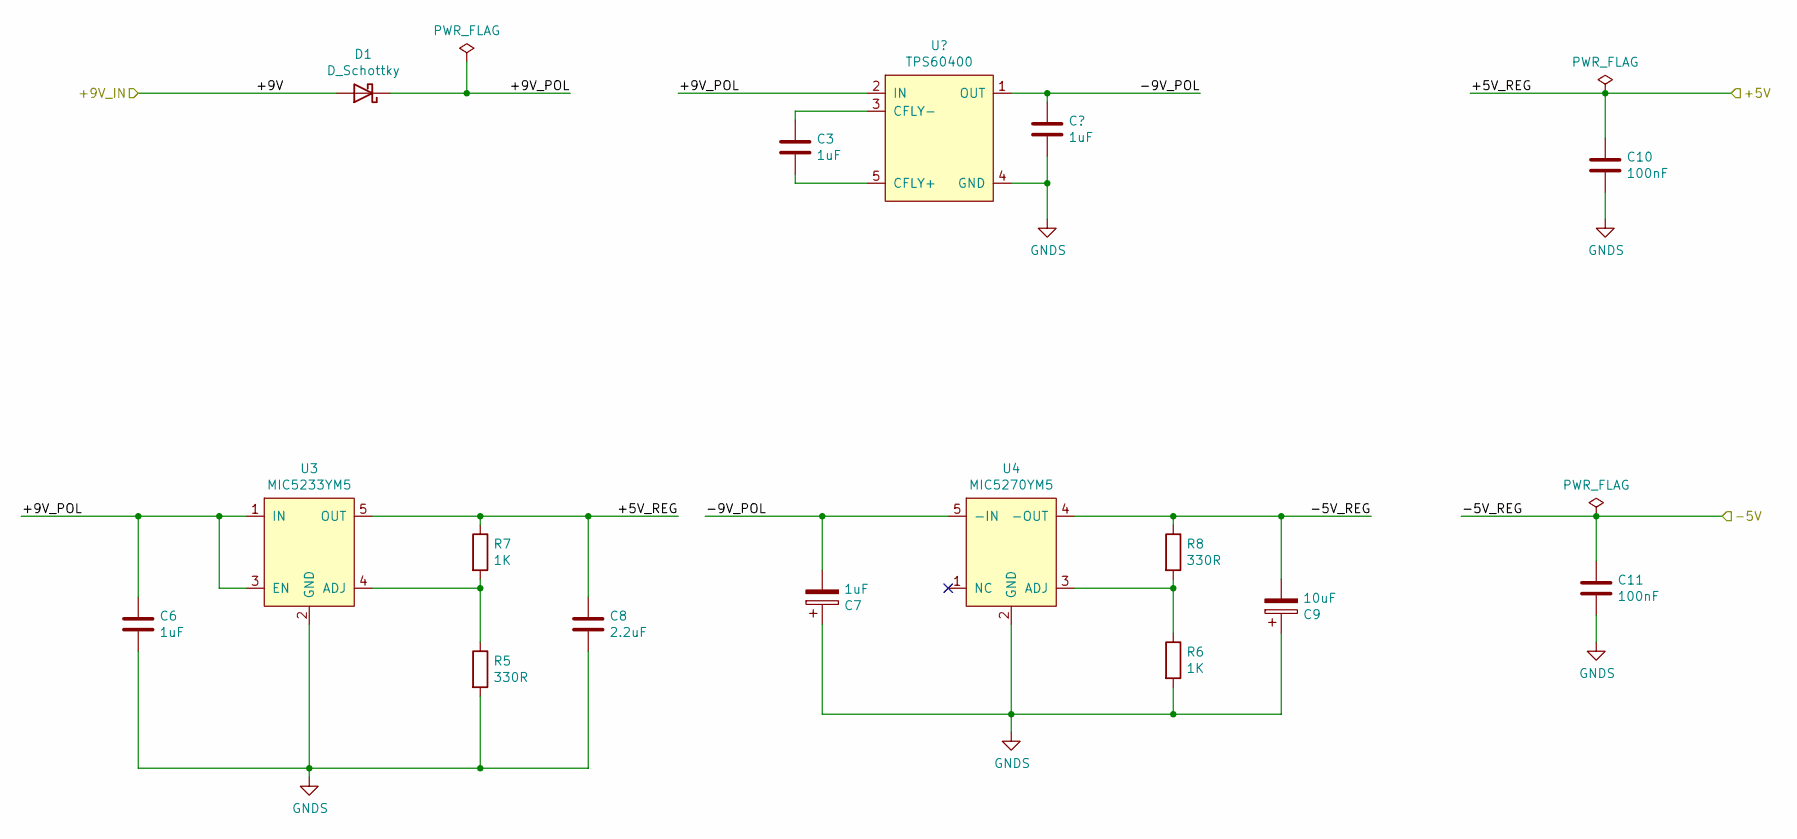
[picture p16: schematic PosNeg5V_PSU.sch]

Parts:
C3, C6: 1uF; C_0805_2012Metric_Pad1.15x1.40mm_HandSolder
C7: 1uF; CP_Elec_4x5.7
C8: 2.2uF; C_0805_2012Metric_Pad1.15x1.40mm_HandSolder
C9: 10uF; CP_Elec_4x5.7
C10, C11: 100nF; C_0805_2012Metric_Pad1.15x1.40mm_HandSolder
D1: D_Schottky; D_SOD-123F
R5, R8: 330R; R_0805_2012Metric_Pad1.15x1.40mm_HandSolder
R6, R7: 1K; R_0805_2012Metric_Pad1.15x1.40mm_HandSolder
U3: MIC5233YM5; SOT-23-5_HandSoldering
U4: MIC5270YM5; SOT-23-5_HandSoldering

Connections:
+5V: C8.1, C10.1, R7.1, U3.5 (OUT); also elsewhere on the board
-5V: C9.2, C11.1, R8.1, U4.4 (-OUT); also elsewhere on the board
/PosNeg5V_PSU/+9V_IN: D1.2 (A); also elsewhere on the board
/PosNeg5V_PSU/+9V_POL: C3.1, C6.1, D1.1 (K), U3.1 (IN), U3.3 (EN); also elsewhere on the board
/PosNeg5V_PSU/-9V_POL: C7.2, U4.5 (-IN); also elsewhere on the board
GNDS: C3.2, C6.2, C7.1, C8.2, C9.1, C10.2, C11.2, R5.2, R6.2, U3.2 (GND), U4.2 (GND); also elsewhere on the board
unnamed: R5.1, R7.2, U3.4 (ADJ)
unnamed: R6.1, R8.2, U4.3 (ADJ)

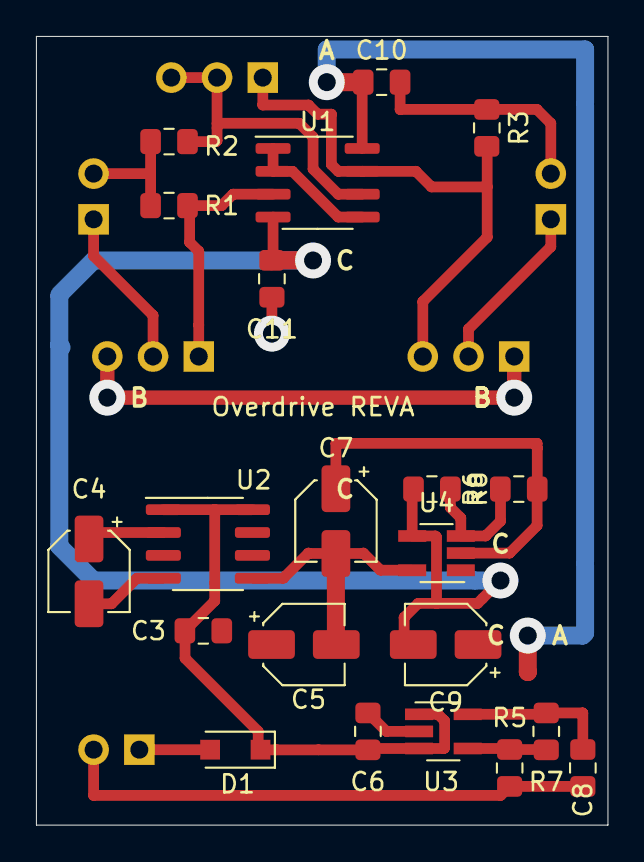
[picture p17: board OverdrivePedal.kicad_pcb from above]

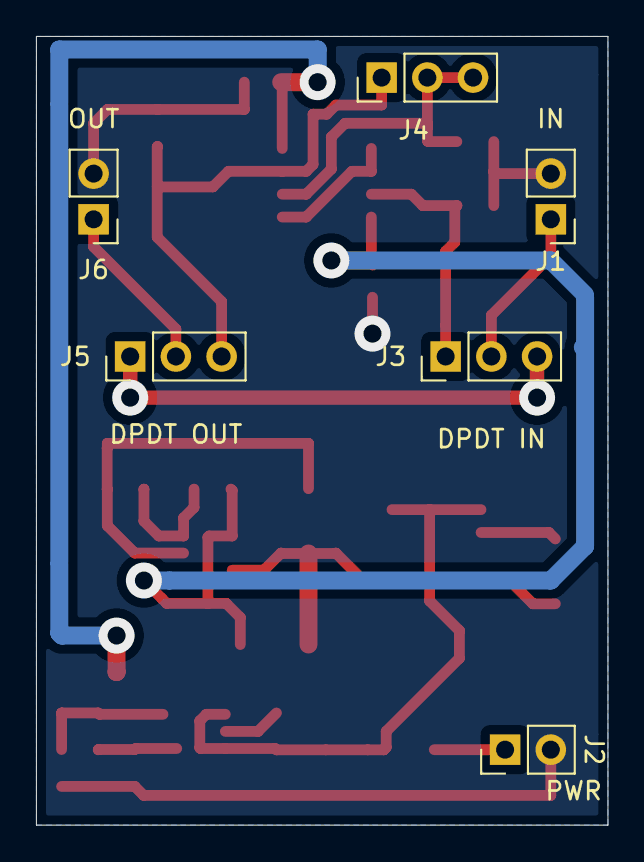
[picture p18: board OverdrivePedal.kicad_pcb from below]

Board: 2 copper layers, 31.8 x 43.8 mm, 27 parts (6 on the bottom side), 17 nets.

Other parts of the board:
C4, C5: 10uF; CP_Elec_4x5.7
U2: TC7662Bx0A; SOIC-8_3.9x4.9mm_P1.27mm

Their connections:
/PosNeg5V_PSU/+9V_POL: U2.1, U2.8; also elsewhere on the board
/PosNeg5V_PSU/-9V_POL: C5.2, U2.5; also elsewhere on the board
GNDS: C5.1, U2.3; also elsewhere on the board
unnamed: C4.1, U2.2
unnamed: C4.2, U2.4

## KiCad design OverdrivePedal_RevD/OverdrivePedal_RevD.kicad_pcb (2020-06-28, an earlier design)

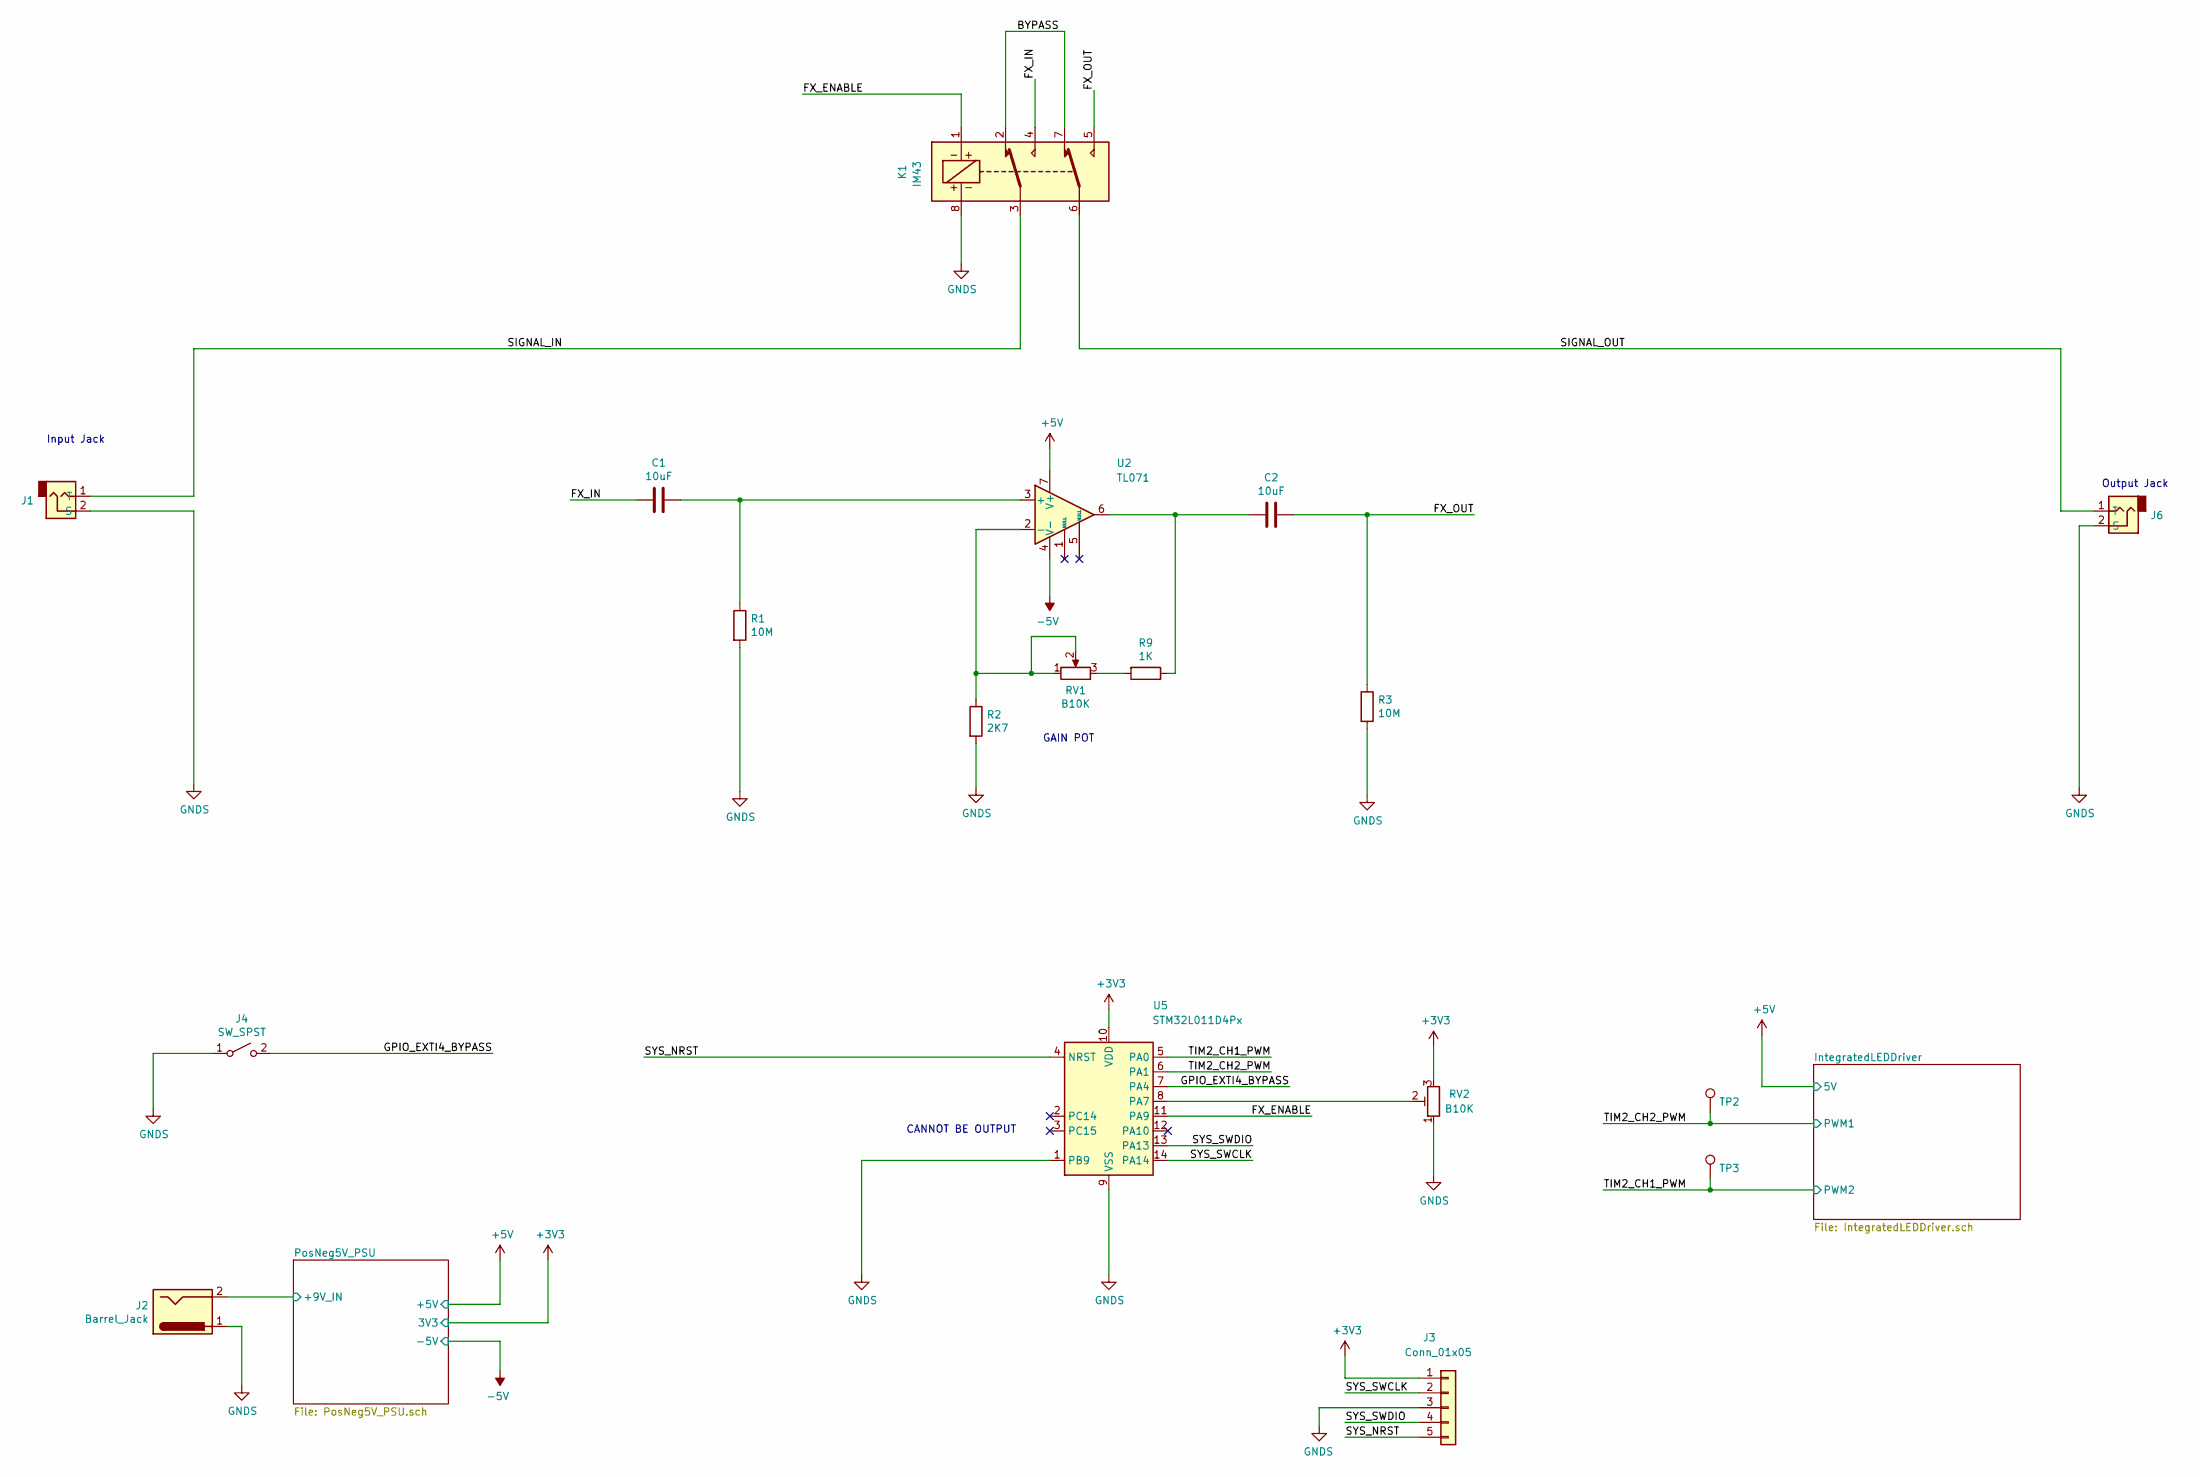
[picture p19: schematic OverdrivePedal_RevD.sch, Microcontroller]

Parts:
C1, C2: 10uF; C_0402_1005Metric
J1, J6: AudioJack2-Connector; PinSocket_1x02_P2.54mm_Vertical
J2: Barrel_Jack; PinHeader_1x02_P2.54mm_Vertical
J3: Conn_01x05; PinHeader_1x05_P1.27mm_Vertical
J4: SW_SPST; PinSocket_1x02_P2.54mm_Vertical
K1: IM43; Relay_DPDT_AXICOM_IMSeries_Pitch5.08mm
R1, R3: 10M; R_0402_1005Metric
R2: 2K7; R_0402_1005Metric
R9: 1K; R_0402_1005Metric
RV1: B10K; PinHeader_1x03_P2.54mm_Vertical
RV2: B10K; Potentiometer_Vishay_T73XW_Horizontal
TP2, TP3: TestPoint; TestPoint_Pad_1.0x1.0mm
U2: TL071; SOIC-8_3.9x4.9mm_P1.27mm
U5: STM32L011D4Px; TSSOP-14_4.4x5mm_P0.65mm

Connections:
+3V3: J3.1, RV2.3, U5.10 (VDD); also elsewhere on the board
+5V: U2.7 (V+); also elsewhere on the board
-5V: U2.4 (V-); also elsewhere on the board
/BYPASS: K1.2, K1.7
/FX_ENABLE: K1.1, U5.11 (PA9)
/FX_IN: C1.2, K1.4
/FX_OUT: C2.1, K1.5, R3.1
/GPIO_EXTI4_BYPASS: J4.2 (B), U5.7 (PA4)
/PosNeg5V_PSU/+9V_IN: J2.2; also elsewhere on the board
/SIGNAL_IN: J1.1 (T), K1.3
/SIGNAL_OUT: J6.1 (T), K1.6
/SYS_NRST: J3.5, U5.4 (NRST)
/SYS_SWCLK: J3.2, U5.14 (PA14)
/SYS_SWDIO: J3.4, U5.13 (PA13)
/TIM2_CH1_PWM: TP3.1, U5.5 (PA0); also elsewhere on the board
/TIM2_CH2_PWM: TP2.1, U5.6 (PA1); also elsewhere on the board
GNDS: J1.2 (S), J2.1, J3.3, J4.1 (A), J6.2 (S), K1.8, R1.2, R2.2, R3.2, RV2.1, U5.1 (PB9), U5.9 (VSS); also elsewhere on the board
unnamed: C1.1, R1.1, U2.3 (+)
unnamed: C2.2, R9.1, U2.6
unnamed: R2.1, RV1.1, RV1.2, U2.2 (-)
unnamed: R9.2, RV1.3
unnamed: RV2.2, U5.8 (PA7)

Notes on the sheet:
GAIN POT
Output Jack
Input Jack
CANNOT BE OUTPUT

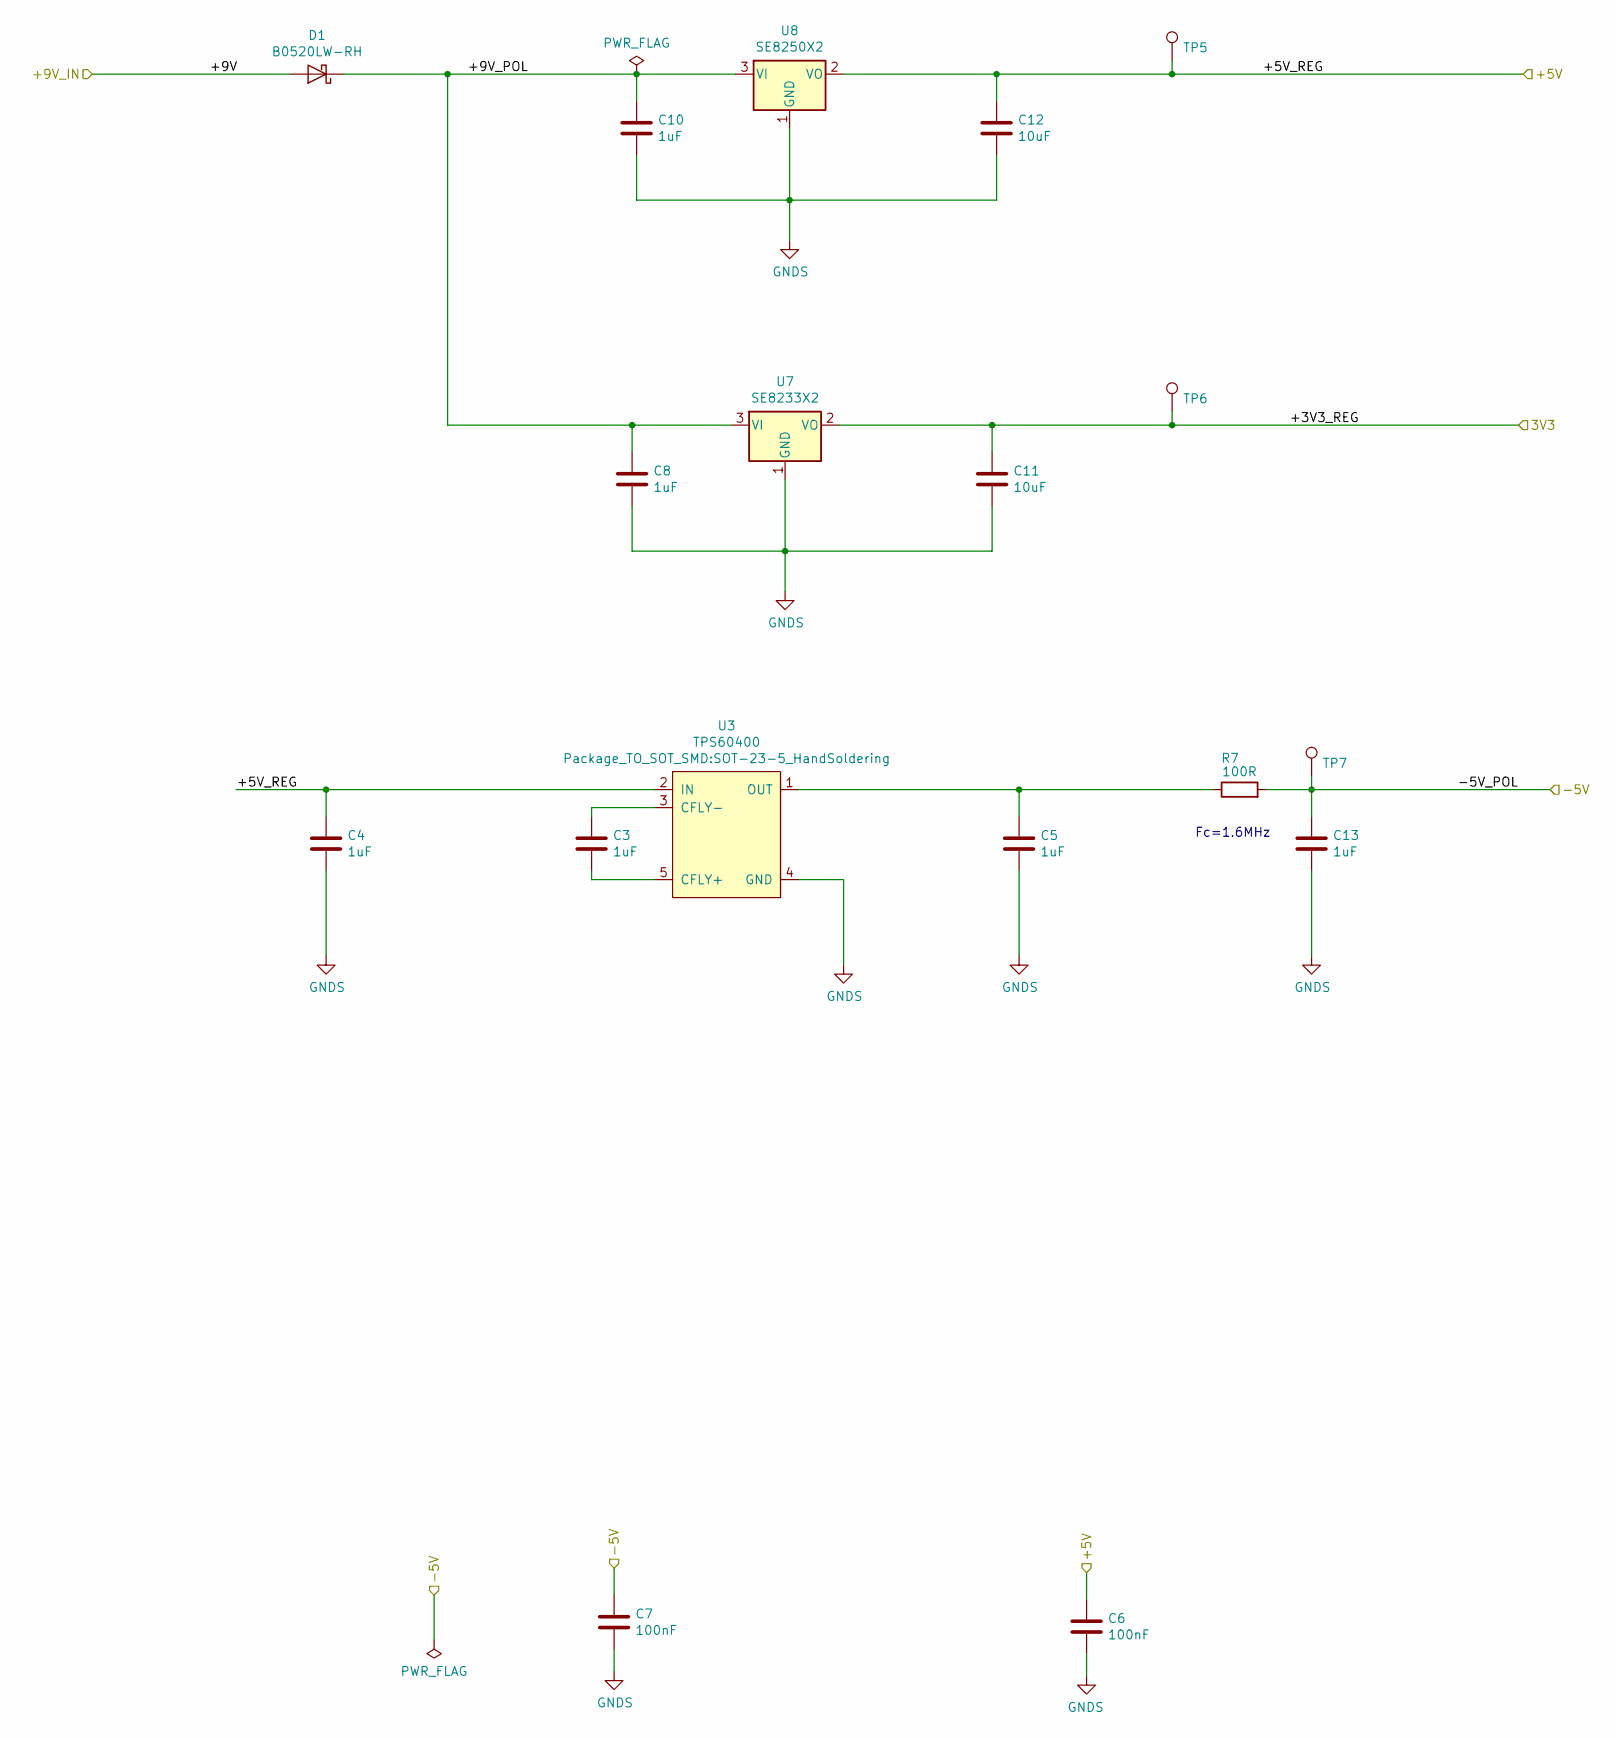
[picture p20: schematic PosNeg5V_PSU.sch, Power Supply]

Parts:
C3, C4, C5, C13: 1uF; C_0402_1005Metric
C6, C7: 100nF; C_0402_1005Metric
C8, C10: 1uF; C_0805_2012Metric_Pad1.15x1.40mm_HandSolder
C11, C12: 10uF; C_0402_1005Metric
D1: B0520LW-RH; D_SOD-123F
R7: 100R; R_0402_1005Metric
TP5, TP6, TP7: TestPoint; TestPoint_Pad_1.0x1.0mm
U3: TPS60400; SOT-23-5_HandSoldering
U7: SE8233X2; SOT-23
U8: SE8250X2; SOT-23

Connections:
+3V3: C11.1, TP6.1, U7.2 (VO); also elsewhere on the board
+5V: C4.1, C6.1, C12.1, TP5.1, U3.2 (IN), U8.2 (VO); also elsewhere on the board
-5V: C7.1, C13.1, R7.2, TP7.1; also elsewhere on the board
/PosNeg5V_PSU/+9V_IN: D1.2 (A); also elsewhere on the board
/PosNeg5V_PSU/+9V_POL: C8.1, C10.1, D1.1 (K), U7.3 (VI), U8.3 (VI)
GNDS: C4.2, C5.2, C6.2, C7.2, C8.2, C10.2, C11.2, C12.2, C13.2, U3.4 (GND), U7.1 (GND), U8.1 (GND); also elsewhere on the board
unnamed: C3.1, U3.3 (CFLY-)
unnamed: C3.2, U3.5 (CFLY+)
unnamed: C5.1, R7.1, U3.1 (OUT)

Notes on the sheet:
Fc=1.6MHz

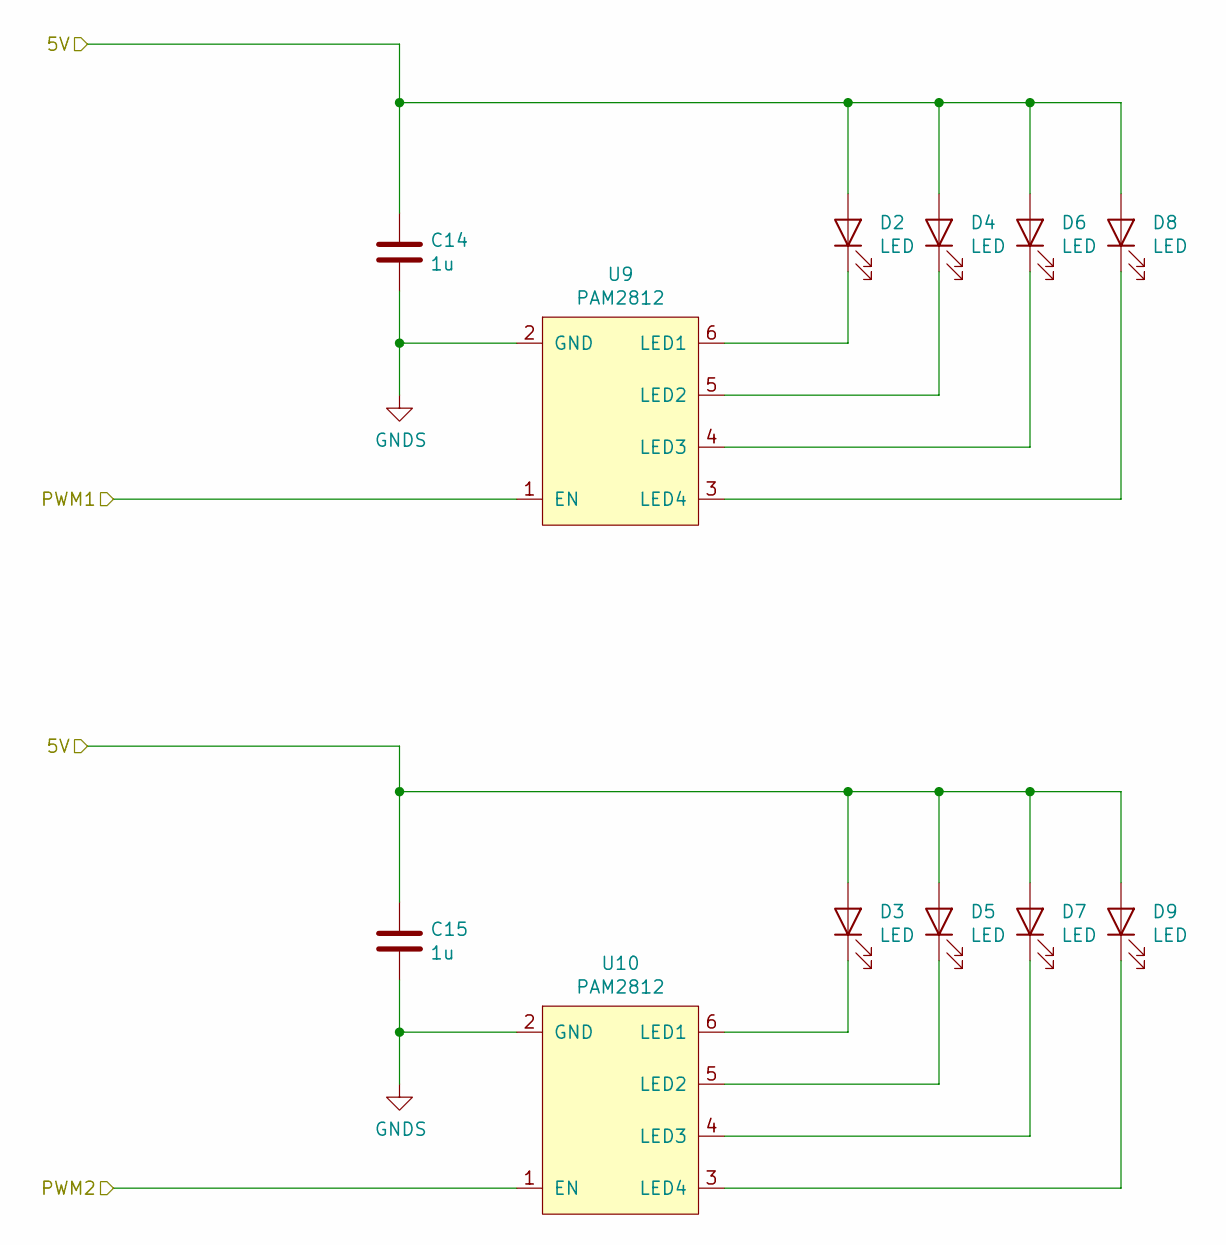
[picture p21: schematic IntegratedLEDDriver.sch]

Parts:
C14, C15: 1u; C_0402_1005Metric
D2, D3, D4, D5, D6, D7, D8, D9: LED; LED_1206_3216Metric_Pad1.42x1.75mm_HandSolder
U9, U10: PAM2812; TSOT-23-6_HandSoldering

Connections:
+5V: C14.1, C15.1, D2.2 (A), D3.2 (A), D4.2 (A), D5.2 (A), D6.2 (A), D7.2 (A), D8.2 (A), D9.2 (A); also elsewhere on the board
/TIM2_CH1_PWM: U10.1 (EN); also elsewhere on the board
/TIM2_CH2_PWM: U9.1 (EN); also elsewhere on the board
GNDS: C14.2, C15.2, U9.2 (GND), U10.2 (GND); also elsewhere on the board
unnamed: D2.1 (K), U9.6 (LED1)
unnamed: D3.1 (K), U10.6 (LED1)
unnamed: D4.1 (K), U9.5 (LED2)
unnamed: D5.1 (K), U10.5 (LED2)
unnamed: D6.1 (K), U9.4 (LED3)
unnamed: D7.1 (K), U10.4 (LED3)
unnamed: D8.1 (K), U9.3 (LED4)
unnamed: D9.1 (K), U10.3 (LED4)

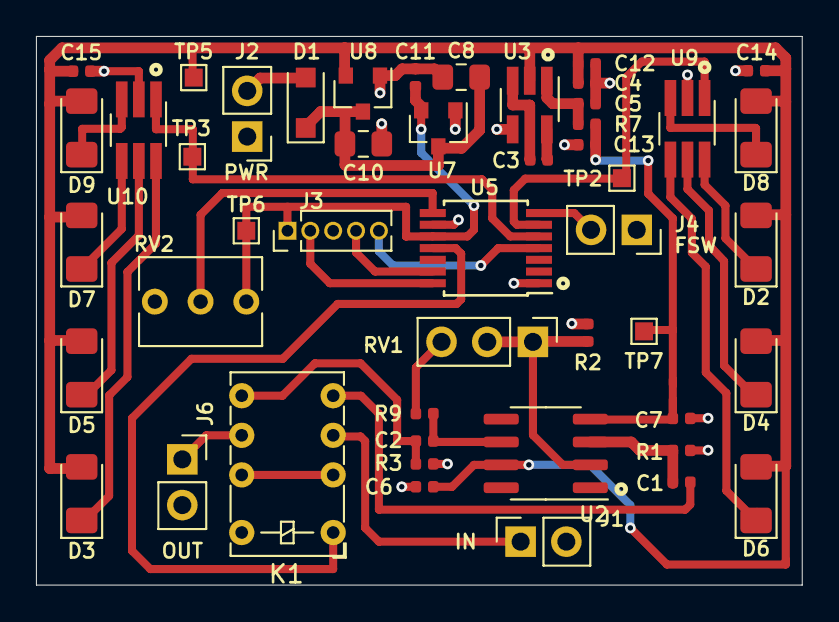
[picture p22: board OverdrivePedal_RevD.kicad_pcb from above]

Board: 2 copper layers, 42.5 x 30.5 mm, 48 parts (0 on the bottom side), 34 nets.

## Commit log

2020-03-04 First Schema design
    [OverdrivePedal.kicad_pcb, OverdrivePedal.sch, PosNeg5V_PSU.sch]
2020-03-04 RevA Layout completed
    [OverdrivePedal.sch, PosNeg5V_PSU.sch]
2020-03-08 Replaced TL071 with TL072
    UPDATED LAYOUT
    [OverdrivePedal.kicad_pcb, OverdrivePedal.sch]
2020-03-09 Tested RevA Layout
    - Removed AC coupling caps
    - Reversed Switch connector
    [OverdrivePedal.kicad_pcb, OverdrivePedal.sch, PosNeg5V_PSU.sch]
2020-03-10 RevB Layout completed
    [OverdrivePedal_RevB.kicad_pcb, OverdrivePedal_RevB.sch, PosNeg5V_PSU.sch]
2020-03-10 modified RevB
    [OverdrivePedal_RevB.kicad_pcb, OverdrivePedal_RevB.sch, PosNeg5V_PSU.sch]
2020-03-18 Added 2 x RGB LEDS
    [OverdrivePedal_RevB.sch]
2020-03-20 Added gnd plane revb
    [OverdrivePedal_RevB.kicad_pcb]
2020-03-27 updated revb
    [OverdrivePedal_RevB.kicad_pcb, OverdrivePedal_RevB.sch, PosNeg5V_PSU.sch]
2020-03-27 Added extra leds
    [OverdrivePedal_RevB.kicad_pcb, OverdrivePedal_RevB.sch]
2020-03-28 updated revb design
    - Added solidstate ICs for bypass switching to allow for mom. footswitch
    - Added STM32L011 MCU
    - Added SE82XX (SOT23) LDOs for 5V and 3V3 rails
    [OverdrivePedal_RevB.kicad_pcb, OverdrivePedal_RevB.sch, PosNeg5V_PSU.sch]
2020-03-29 Draft layout completed
    RevB layout
    [DiscreteLEDDriver.sch, IntegratedLEDDriver.sch, LEDController.sch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]
2020-03-29 updated draft
    [OverdrivePedal_RevB.kicad_pcb, OverdrivePedal_RevB.sch, PosNeg5V_PSU.sch]
2020-03-31 RevB layout gerbers submitted
    [OverdrivePedal_RevB-B_Cu.gbr, OverdrivePedal_RevB-B_Mask.gbr, OverdrivePedal_RevB-B_Paste.gbr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]
2020-04-11 updated revc
    - Switch PC15 to PA9 for FX_ENABLE
    - connected BOOT0 to GND
    - Removed U11 charge pump (not required/causing oscillation)
    - lowered U3 charge pump LP filter cuttoff to 1.6KHz
    [DiscreteLEDDriver.sch, IntegratedLEDDriver.sch, LEDController.sch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]
2020-04-12 updated revc
    - Changed ICP header from 2.54 to 1.27
    - Added trim pot connected to ADC IN7 (PA7)
    [OverdrivePedal_RevC.kicad_pcb, OverdrivePedal_RevC.sch]
2020-04-12 Finalized RevC
    [OverdrivePedal_RevB.kicad_pcb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]
2020-04-22 fixed wiring mistake on trim pot
    [OverdrivePedal_RevC.kicad_pcb, OverdrivePedal_RevC.sch]
2020-04-23 Updated RevD layout
    Additional DG468 SPST switch to shunt FX circuit to GND when bypass enabled.
    [DiscreteLEDDriver.sch, IntegratedLEDDriver.sch, LEDController.sch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]
2020-04-24 Modified RevD design to use IM43 Relay instead of DG468 SW
    [OverdrivePedal_RevC.sch, OverdrivePedal_RevD.csv, OverdrivePedal_RevD.kicad_pcb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]
2020-09-17 changed polarity protection mosfet to schotky diode
    [OverdrivePedal.kicad_pcb, OverdrivePedal.sch, PosNeg5V_PSU.sch]
